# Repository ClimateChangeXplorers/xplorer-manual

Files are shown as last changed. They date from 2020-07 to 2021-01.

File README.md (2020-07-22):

# Xplorer Manual

The process for building your station follows 5 major steps:

1. [PLAN](/plan): in this step you will plan out the design of your
   station. The components, sensors, physical design, etc. will all be
   taken into account during this phase.
2. [BUILD](./build): in this step you will begin the building process.
   You will gather your frame parts, wires, and PVC and build the frame
   so it is ready for your sensors and microcontrollers.
3. [FLASH](./flash): in this step you will build the source files and
   flash them onto your device. Should you want to flash the binaries
   directly, there are instructions to do so.
4. [TEST](./test): making sure each node works as expected will insure
   the best experience for your deployment.
5. [DEPLOY](./deploy): siting and deploying are the final step in
   getting you on your way to your first 3d-printed automated weather
   station.

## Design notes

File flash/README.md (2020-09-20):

# Flashing Microcontrollers

Each station node is build atop a microcontroller, where each
microcontroller is connected to one or more sensors either directly or
by [Grove hubs](https://www.seeedstudio.com/Grove-I2C-Hub.html). 

The CCX system is designed to be used with the [m5Stack Atom Lite](https://m5stack.com/collections/m5-core/products/atom-lite-esp32-development-kit)
ESP32-Pico based microcontroller.  

There are two nodes that the core Arduino code has been developed for.
Before compiling the microcode onto the Arduino, you will also need to
install the core IoTwx shared library which controls many of the
communications and initialization functions of each node.

This core library can found at the following repository. It should be
installed in your `Arduiono/libraries` directory and once installed, you
may use it by the `#include "IoTwx.h"` directive.

* [https://github.com/NCAR/esp32-atomlite-arduino-iotwx](https://github.com/NCAR/esp32-atomlite-arduino-iotwx)

Please see the
[parts list](https://drive.google.com/file/d/1Hnn0Ms2DzVQgRFmGBpLQ9W2NGEz2gopc/view?usp=sharing)
for the microcontroller, sensors and cables required or recommended to
build and connect a base system.

## Preparing Your System

You will need to install the [latest version of Arduino](https://www.arduino.cc/en/Main/Software) on your system to begin.

There are a few other steps you will need to complete:

* install the required ESP32 Pico / M5 Stack Atom lite boards; a comprehensive instruction set is [here](https://docs.m5stack.com/#/en/arduino/arduino_development)
* install the [arduino-esp32fs-plugin](https://github.com/me-no-dev/arduino-esp32fs-plugin) that will allow SPIFFS file uploads to ESP32 boards
* install the following libraries through the Arduino IDE:
   * MQTT library from 256dpi [https://github.com/256dpi/arduino-mqtt](https://github.com/256dpi/arduino-mqtt)
   * SeeedStudio VEML6070 library [https://github.com/Seeed-Studio/Seeed_VEML6070](https://github.com/Seeed-Studio/Seeed_VEML6070)
   * SeeedStudio BME280 library [https://github.com/Seeed-Studio/Grove_BME280](https://github.com/Seeed-Studio/Grove_BME280)
   * SeeedStudio BME680 library [https://github.com/Seeed-Studio/Seeed_BME680](https://github.com/Seeed-Studio/Seeed_BME680)
   * ArduinoJson library [https://github.com/bblanchon/ArduinoJson](https://github.com/bblanchon/ArduinoJson)
   * FastLED library [https://github.com/FastLED/FastLED](https://github.com/FastLED/FastLED)
   * NTPClient library [https://github.com/arduino-libraries/NTPClient](https://github.com/arduino-libraries/NTPClient)

## Atmos Node 

The Atmos node is comprised of two sensors and two 3d-printed housing
units. The first sensor houses the atmospheric conditions for air
temperature, humidity and barometric pressure. It can be fitted with the
[Seeedstudio BME280 Grove](https://www.seeedstudio.com/Grove-BME280-Environmental-Sensor-Temperature-Humidity-Barometer.html)
environmental sensor, or if you would like to obtain aggregate VOC
measurements, you can fit the housing with the
[BME680 Grove](https://www.seeedstudio.com/Grove-Temperature-Humidity-Pressure-and-Gas-Sensor-for-Arduino-BME680.html)
sensor. The code is designed to work with both sensors (but not
simultaneously). These parts can be found in the
[parts list](https://drive.google.com/file/d/1Hnn0Ms2DzVQgRFmGBpLQ9W2NGEz2gopc/view?usp=sharing).

### Radiation Shield

atmos node

The radiation shield sensor captures the following measurements:
temperature, humidity, barometric pressure, and optionally VOC (if using
the BME680 sensor).

**PRINTING**

* the radiation shield design 3d print files can be found in the
  [`/build/stl/atmos`](https://github.com/ClimateChangeXplorers/xplorer-manual/tree/master/build/stl/atmos) page. If you need to
  print, you will need to follow the instructions there to print the
  housing.

**FLASHING**

* the code to flash the node can be found in the
  [esp32-atomlite-arduino-atmos-node repository](https://github.com/NCAR/esp32-atomlite-arduino-atmos-node).
  You will to follow the instructions there to understand the Arduino
  flashing requirements and procedures.

### UV 

Because the UV measurement is part of the Atmos node, the code already
includes the capability to capture and transmit measurements. It is
integrated in to the
[esp32-atomlite-arduino-atmos-node repository](https://github.com/NCAR/esp32-atomlite-arduino-atmos-node)
and hence no other changes or files are necessary to flash once that
file has been uploaded to the microcontroller.

## Hydro Node

hydro node
 
The hydro node is designed to collected and transmit precipitation
measurements.  

**PRINTING** 

* the rain gauge design 3d print files can be found in the
  [`/build/stl/hydro`](https://github.com/ClimateChangeXplorers/xplorer-manual/tree/master/build/stl/hydro)
  page. If you need to print, you will need to follow the instructions
  there to print the housing.

**FLASHING**

* the code to flash the node can be found in the
  [esp32-atomlite-arduino-hydro-node repository](https://github.com/NCAR/esp32-atomlite-arduino-hydro-node).
  You will to follow the instructions there to understand the Arduino
  flashing requirements and procedures.

## Aero Node

aero node

The aero node is designed to collect wind vane & anemometer wind speed
and direction.

* Instructions for printing and flashing are forthcoming.

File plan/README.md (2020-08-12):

# Planning your station

In general, planning your station is easy. While we recommend you use PVC for the 
main frame of the station, you may use any materials you like as long as they bind to 
the ABS/PLA plastic of the 3D-printed parts.

The base configuration of the station includes three nodes and the power (we'll 
consider the power a node as well moving forward).  You may reduce or expand those 
nodes based on your specific needs, but the base configuration will be assumed in 
this guide.

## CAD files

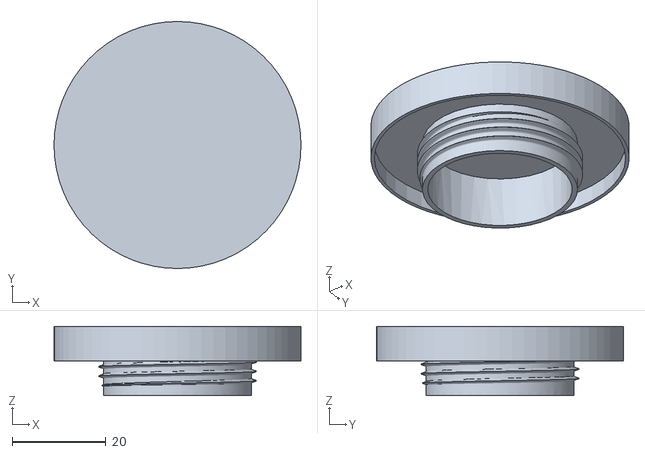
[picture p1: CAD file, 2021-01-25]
build/stl/aero/aero_wnvn_cap_2.stl
52.8 x 52.8 x 14.9

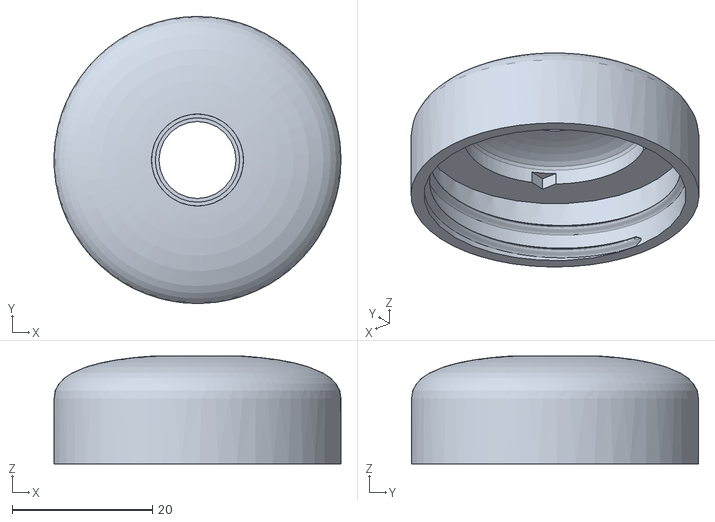
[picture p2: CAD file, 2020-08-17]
build/stl/atmos/uv_cap.stl
41.0 x 41.0 x 15.4

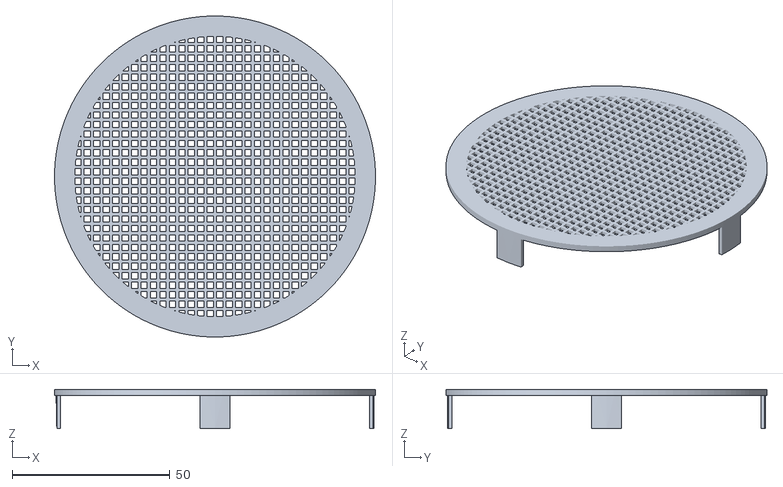
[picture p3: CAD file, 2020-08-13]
build/stl/hydro/hyd_funnel_screen.stl
101.9 x 101.9 x 12.5

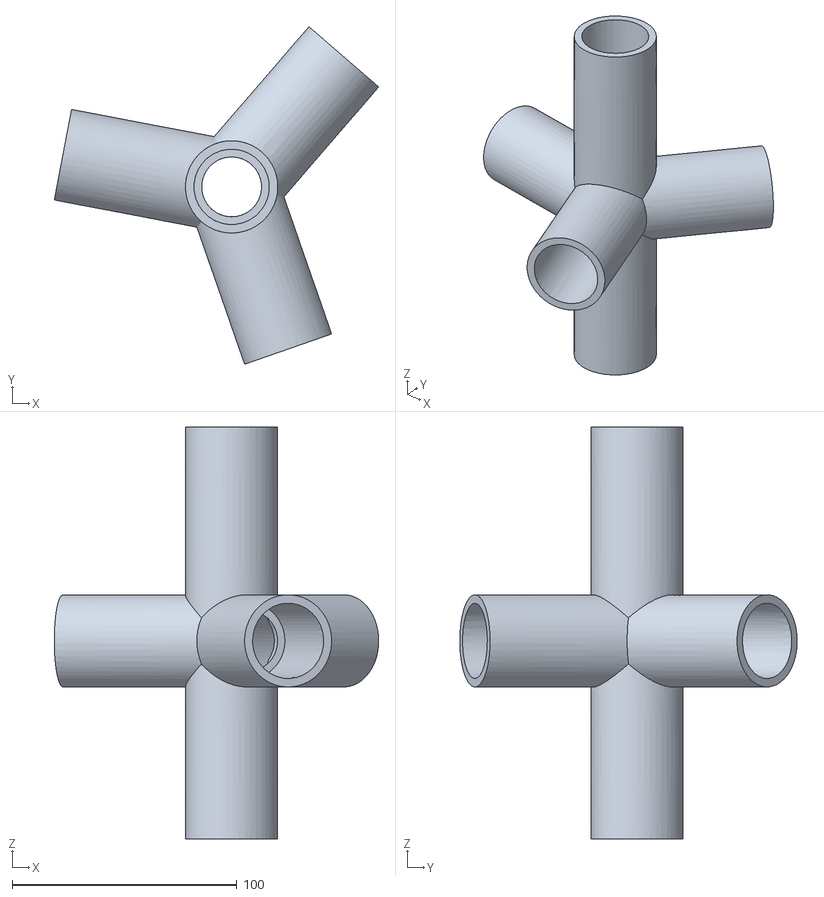
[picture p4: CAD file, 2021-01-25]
build/stl/pvc/pvc_mid_splitter.stl
144.2 x 150.0 x 183.1

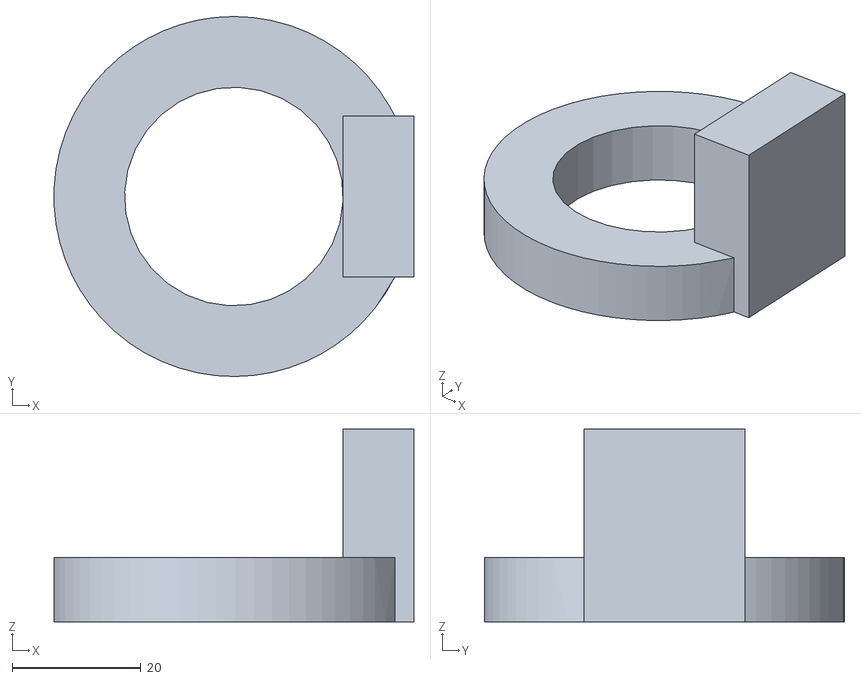
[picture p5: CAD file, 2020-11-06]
build/stl/solar/sol_11mil_clamp.stl
56.0 x 56.0 x 30.0

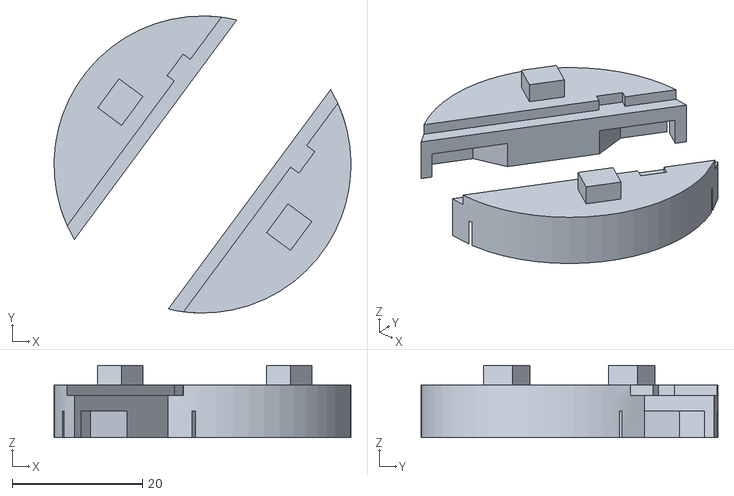
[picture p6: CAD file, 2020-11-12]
build/stl/aero/aero_wnvn_clips_3.stl
45.5 x 45.5 x 11.1

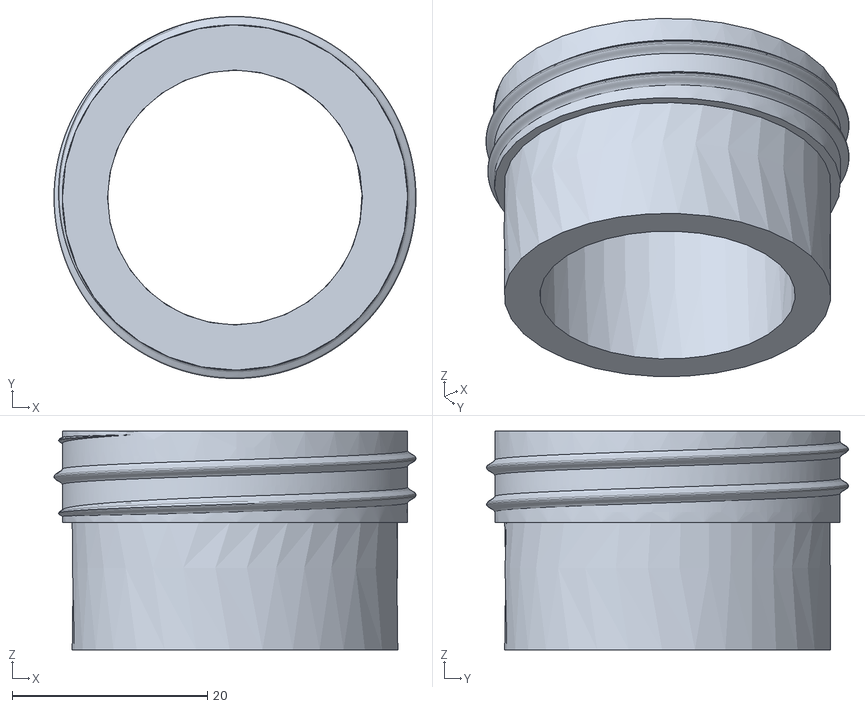
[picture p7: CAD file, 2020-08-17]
build/stl/atmos/uv_tube.stl
37.1 x 37.1 x 22.4

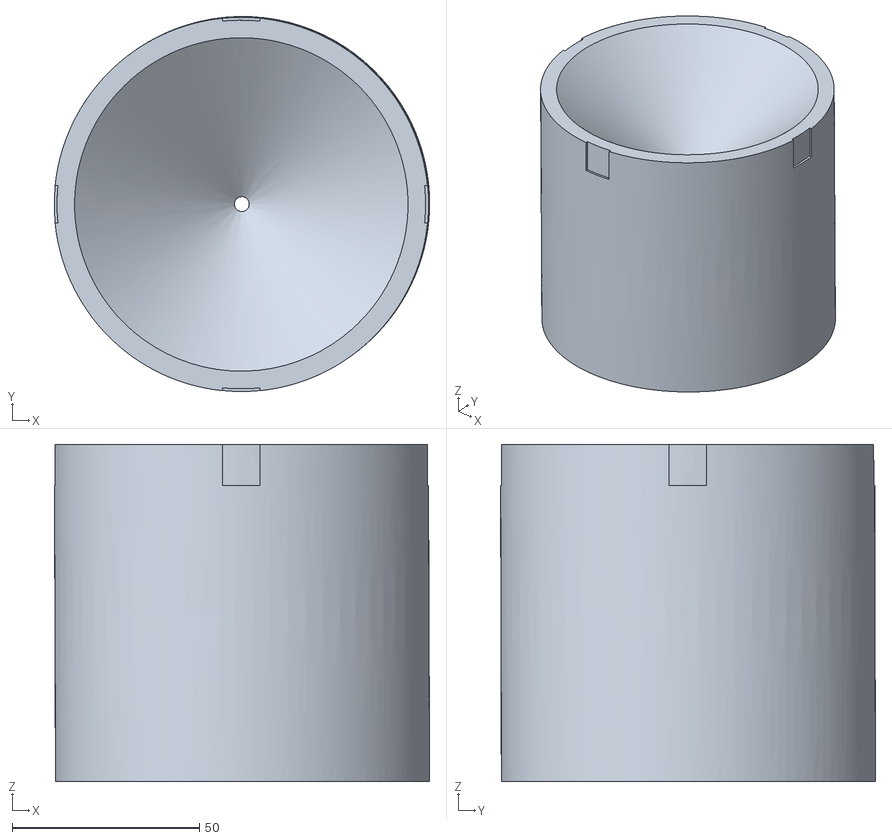
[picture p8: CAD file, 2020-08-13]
build/stl/hydro/hyd_funnel.stl
100.2 x 100.1 x 90.0

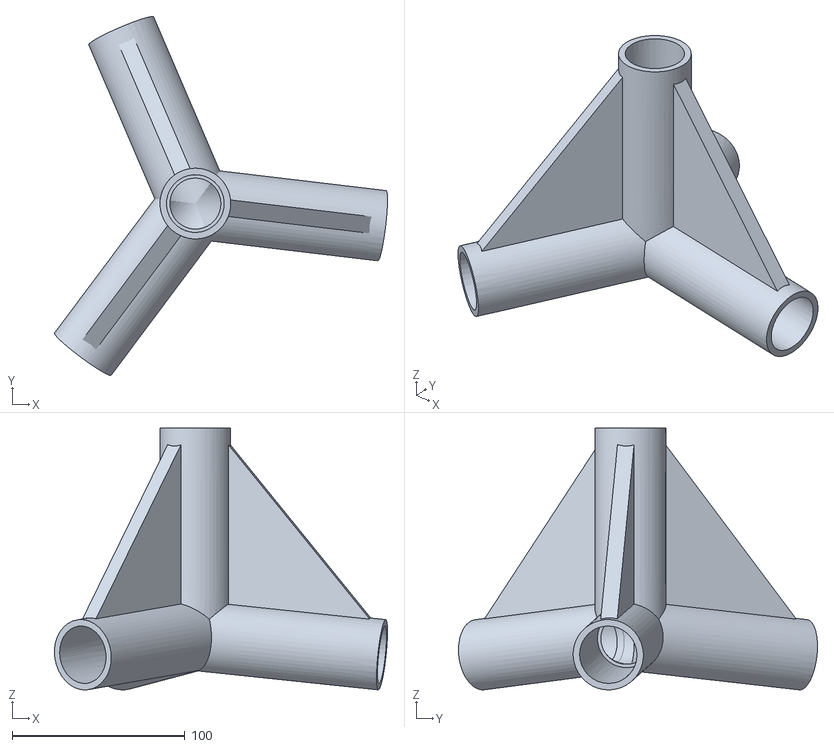
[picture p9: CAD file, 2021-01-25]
build/stl/pvc/pvc_tripod_base_2.stl
193.1 x 208.1 x 151.8

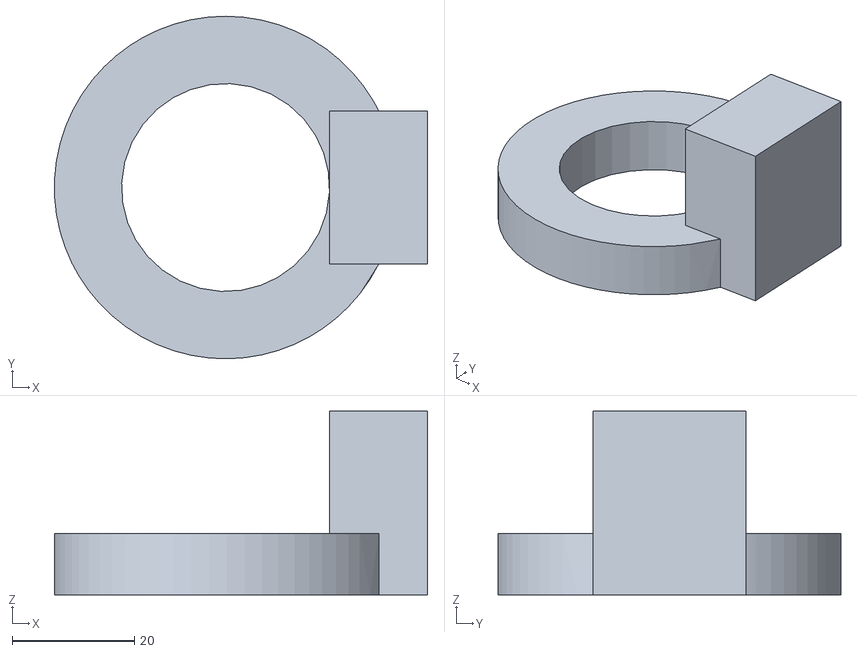
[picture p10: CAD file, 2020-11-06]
build/stl/solar/sol_16mil_clamp.stl
61.0 x 56.0 x 30.0

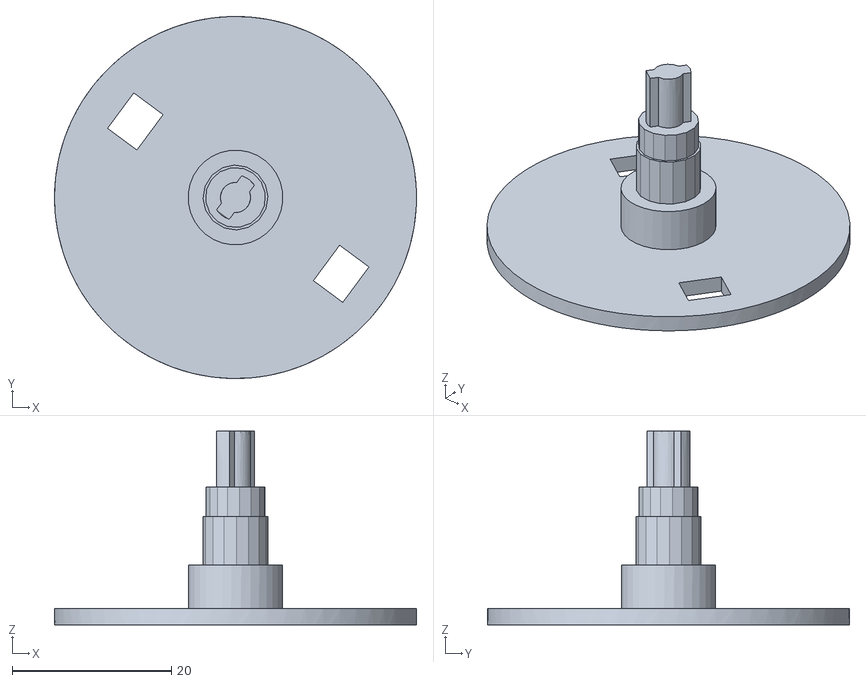
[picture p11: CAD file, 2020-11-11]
build/stl/aero/aero_wnvn_plate_3.stl
45.5 x 45.5 x 24.4

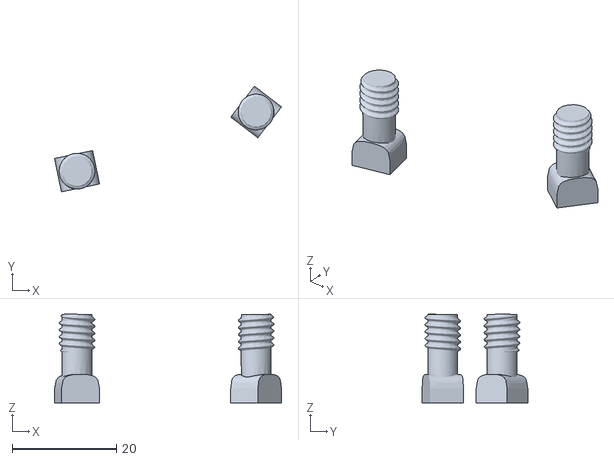
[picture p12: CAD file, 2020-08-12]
build/stl/atmos/rs_fasteners.stl
43.6 x 20.3 x 17.1

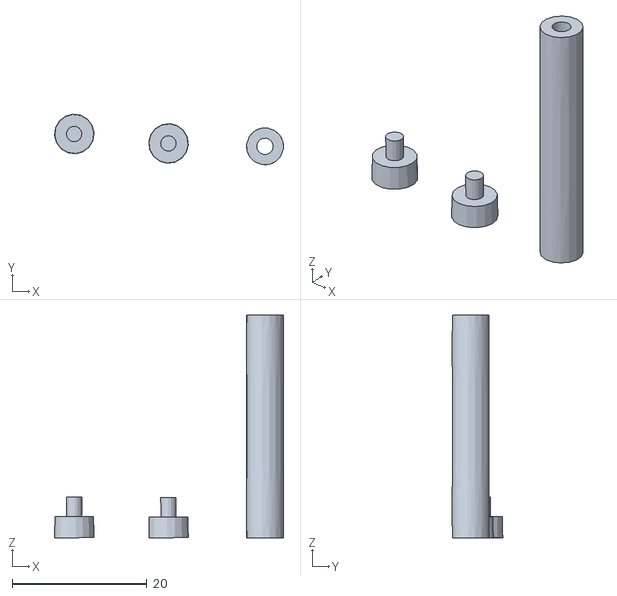
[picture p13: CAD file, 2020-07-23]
build/stl/hydro/hyd_fulcrum.stl
34.0 x 7.52 x 33.1

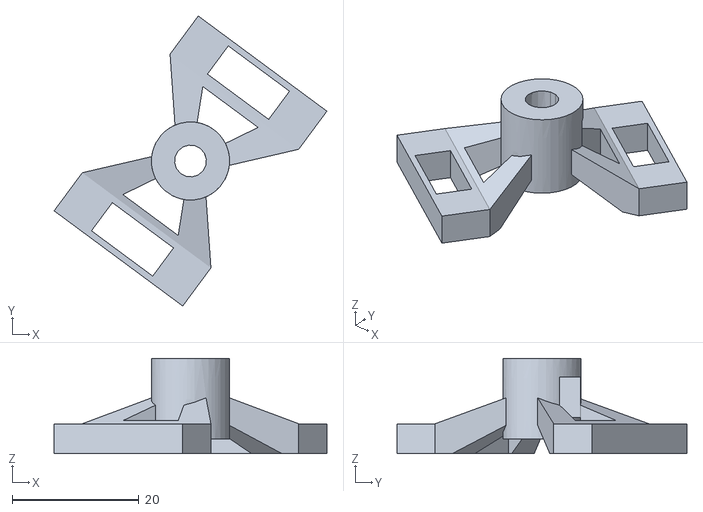
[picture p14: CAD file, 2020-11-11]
build/stl/aero/aero_wnvn_coupler_3.stl
43.1 x 45.8 x 15.0

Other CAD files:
build/stl/pvc/pvc_tri_splitter_2.stl
build/stl/atmos/rs_screen_ring.stl
build/stl/hydro/hyd_rain_guage.stl
build/stl/pvc/pvc_tripod_base_3.stl
build/stl/atmos/rs_base.stl
build/stl/atmos/rs_base_plate.stl
build/stl/atmos/rs_center_screen.stl
build/stl/atmos/rs_clip.stl
build/stl/atmos/rs_shaft.stl
build/stl/atmos/rs_single_leaf.stl
build/stl/atmos/rs_top_leaf.stl
build/stl/pvc/pvc_balljoint_bar.stl
build/stl/pvc/pvc_en_cap.stl
build/stl/pvc/pvc_en_tube.stl
build/stl/pvc/pvc_innerlock.stl
build/stl/pvc/pvc_micro_holder.stl
build/stl/pvc/pvc_outerlock.stl
build/stl/pvc/pvc_stake.stl
build/stl/pvc/pvc_tjoint.stl
build/stl/pvc/pvc_tri_splitter.stl
build/stl/pvc/pvc_tripod_base.stl

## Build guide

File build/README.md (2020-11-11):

# Building Your Station
atmos node

**PARTS LIST**

Before getting started, you should consult the complete list of parts
and hardware that can be found at:

* See the
  [Google spreadsheet](https://drive.google.com/file/d/1Hnn0Ms2DzVQgRFmGBpLQ9W2NGEz2gopc/view?usp=sharing)
  for the full, up-to-date list of _non-printed_ parts for building a
  complete station. The vast majority of parts can be found on Amazon,
  through online electronics distributors and through your local
  hardware store.

**Note:** the base case build has quantities preset to 1 item. Also,
**alternative power options** are also listed in this document for users
interested in further customizing their station to specific power needs.

If you only wish to do tabletop testing, you will only need to follow
the [flash instructions](https://github.com/ClimateChangeXplorers/xplorer-manual/tree/master/flash) for the microcontroller and then proceed to
the [tabletop testing](#skeletontabletop-testing). This will eliminate
the need for making wiring bundles, constructing a PVC frame or printing
the 3d-printed housing.

## 3D-Printing

All parts can be found in the [stl](./stl) folder and in conjection 
with the station assembly instructions.

Reference stations have been produced with PLA+ material, but
ABS and other materials may be used, provided you have 
enough expertise using them.

## Framing

## Wiring

## Station Assembly

You can find the various assembly instructions in the provided PDF files:

* [Aero Node Assembly](./Aero_Node_Assembly.pdf) instruction set
* [Hydro Node Assembly](./Hydro_Node_Assembly.pdf) instruction set
* [Atmos Node Assembly](./Atmos_Node_Assembly.pdf) instruction set

## Skeleton/Tabletop Testing

## Solar Assembly

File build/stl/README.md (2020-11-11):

# STL files for printing

There are directories containing all the STL files necessary to print the 
station.  The following nodes are available for printing.  Please consult
the [parts list](https://drive.google.com/file/d/1Hnn0Ms2DzVQgRFmGBpLQ9W2NGEz2gopc/view?usp=sharing) and [flash instructions](https://github.com/ClimateChangeXplorers/xplorer-manual/tree/master/flash) for the other parts (electronics, etc.) 
and code that are necessary to construct a fully operational node.

* [atmos node files](./atmos) are available for the radiation shield
* [hydro node files](./hydro) are available for the tipping bucket
* [aero node files](./aero) are available for the wind vane and anemometer 
* [solar assembly files](./solar) are available for the solar panel assembly
* [pvc connectors files](./pvc) are available for the pvc connectors

# Acknowledgements

This design would not have been possible without the enumerable contributions of others.

In particular, the Atmos node is inspired by the work of the [3D-PAWS radiation shield assembly](https://sites.google.com/ucar.edu/3dpaws/instruments/radiation-shield) ((c) UCAR/COMET)
from which modifications were made to accommodate different sensor orientations, to allow
for easier insertion of the leaf screens and changes were made to the shaft for 
improved threading and durability. The Hydro node is remixed and modified from the 
original work of [RobWLake's LTB Weather Station](https://www.thingiverse.com/thing:2849562) 
(CC-BY-NC 4.0) -- changes were made to the sensor holder to accommodate a [Grove hall effect sensor](https://wiki.seeedstudio.com/Grove-Hall_Sensor/) and a debris screen, 
as well as sizing modifications so that it is easier to construct.

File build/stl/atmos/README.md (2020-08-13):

# Print Settings

Unless otherwise noted, **infill default is 50%**.

| Description | File | Quantity | Notes |
|---|---|---|---|
| Base | [rs_base.stl](./rs_base.stl) | 1 | |
| Center Screen | [rs_center_screen.stl](./rs_center_screen.stl) | 1 | |
| Sensor clip holder | [rs_clip.stl](./rs_clip.stl) | 1 | Print more than 1 if you have multiples or need extras. |
| Middle leaf | [rs_mid_leaf.stl](./rs_mid_leaf.stl) | 1 | |
| Screen Ring | [rs_screen_ring.stl](./rs_screen_ring.stl) | 4 | |
| Center shaft | [rs_shaft.stl](./rs_shaft.stl) | 1 | Print at 100% infill |
| Single leaf | [rs_single_leaf.stl](./rs_single_leaf.stl) | 1 | |
| Top leaf | [rs_top_leaf.stl](./rs_top_leaf.stl) | 1 | |
| Base Fasteners | [rs_fasteners.stl](./rs_fasteners.stl) | 2 | Print at 100% infill; print extras as needed. |  | |
| Swivel ball joint connector | [swvl_balljoint_bar.stl](./swvl_balljoint_bar.stl) | 1 | |
| Swivel ball joint inner locl |[swvl_innerlock.stl](./swvl_innerlock.stl) | 1 | |
| Swivel ball joint outer lock | [swvl_outerlock.stl](./swvl_outerlock.stl) | 1 | |
| Microcontroller holder  | [pvc_micro_holder.stl](./pvc_micro_holder.stl) | 1 | |

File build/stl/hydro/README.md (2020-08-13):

# Print Settings

Unless otherwise noted, **infill default is 50%**.

| Description | File | Quantity | Notes |
|---|---|---|---|
| Fulcrum | [hyd_fulcrum.stl](./hyd_fulcrum.stl) | 1 | Print more than 1 if you need extras |
| Funnel Screen | [hyd_funnel_screen.stl](./hyd_funnel_screen.stl) | 1 | |
| Funnel | [hyd_funnel.stl](./hyd_funnel.stl) | 1 |  |
| Rain gauge | [hyd_rain_guage.stl](./hyd_rain_guage.stl) | 1 | |
| Sensor Slot | [hyd_sensor_slot.stl](./hyd_sensor_slot.stl) | 1 |  |
| Swivel ball joint connector | [swvl_balljoint_bar.stl](./swvl_balljoint_bar.stl) | 1 | |
| Swivel ball joint inner locl |[swvl_innerlock.stl](./swvl_innerlock.stl) | 1 | |
| Swivel ball joint outer lock | [swvl_outerlock.stl](./swvl_outerlock.stl) | 1 | |
| Microcontroller holder  | [pvc_micro_holder.stl](./pvc_micro_holder.stl) | 1 | |

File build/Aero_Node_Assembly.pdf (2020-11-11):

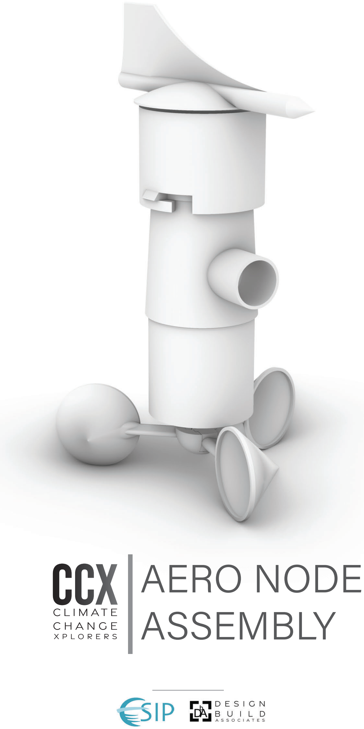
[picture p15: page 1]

# AERO NODE ASSEMBLY Climate

Change
xplorers

# CCX

Climate
Change
xplorers

## EXPLODED COMPONENTS

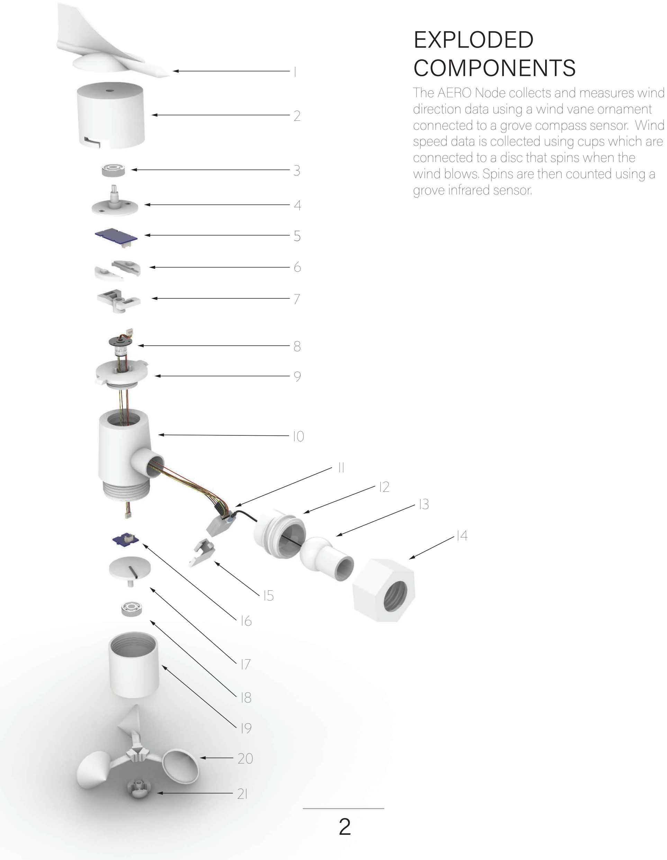
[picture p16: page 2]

The AERO Node collects and measures wind direction data using a wind vane ornament connected to a grove compass sensor. Wind speed data is collected using cups which are connected to a disc that spins when the wind blows. Spins are then counted using a grove infrared sensor.

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
## COMPONENTS LIST

## ASSEMBLY

# | DESCRITION | QUANTITY

1 | Ornament | 1
2 | Wind Vane Hull | 1
3 | Wind Vane Bearing | 1
4 | Wind Vane Plate | 1
5 | Grove Compass Sensor | 1
6 | Wind Vane Plate Clips | 1
7 | Wind Vane Coupler | 1
8 | Comidox Slip Ring Capsole | 1
9 | Wind Vane Cap | 1
10 | Center Hull | 1
11 | Microprocessor | 1
12 | Swivel Innerlock | 1
13 | Swivel Ball Joint Bar | 1
14 | Swivel Outerlock | 1
15 | Micro Harness | 1
16 | Wind Speed Plate | 1
17 | Grove Infrared Sensor | 1
18 | Wind Speed Bearing | 1
19 | Wind Speed Hull | 1
20 | Wind Speed Cups | 1
21 | Wind Speed Cup Connector | 1

# STEP 1

Align the slots on the cap connector with the groves on the cups and connect them one at a time.

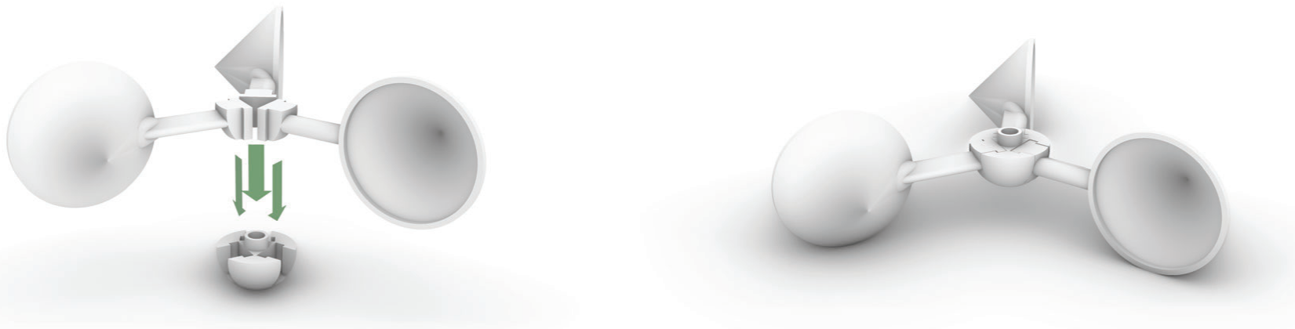
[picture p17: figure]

## ASSEMBLY

# STEP 2

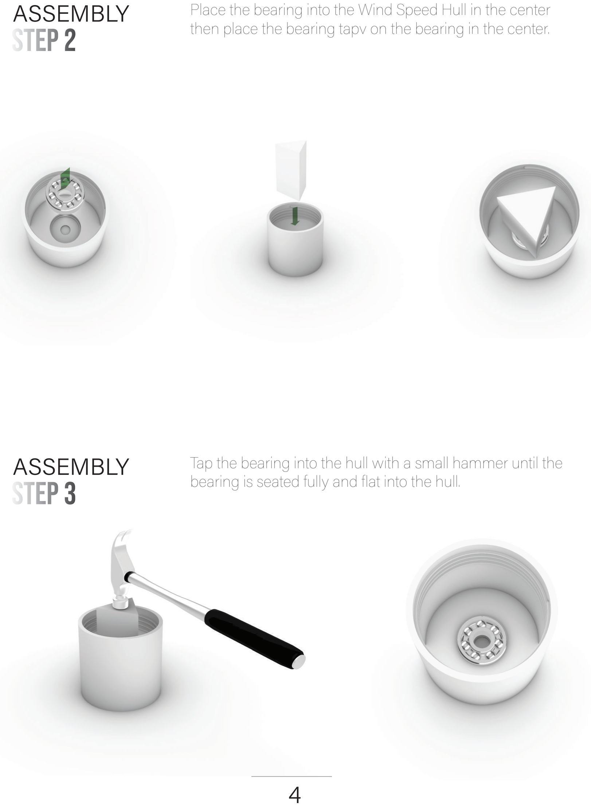
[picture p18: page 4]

## ASSEMBLY

# STEP 3

Tap the bearing into the hull with a small hammer until the bearing is seated fully and flat into the hull.

Place the bearing into the Wind Speed Hull in the center then place the bearing tapv on the bearing in the center.

# STEP 4

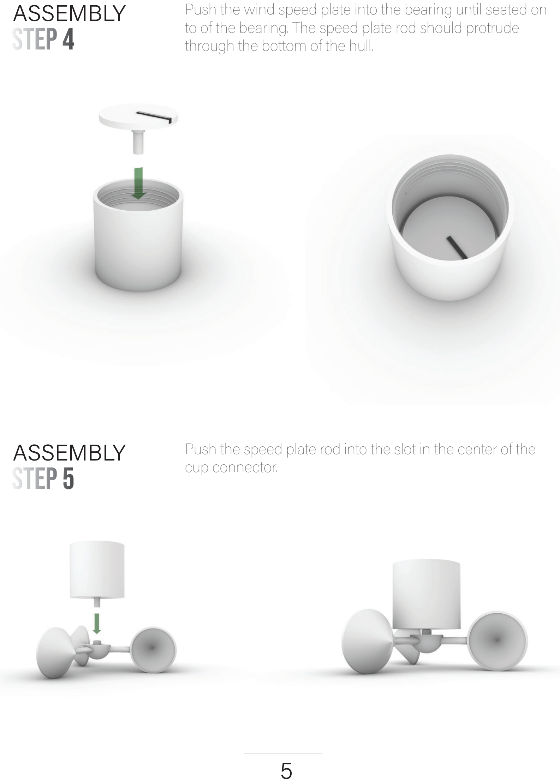
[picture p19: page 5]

## ASSEMBLY

# STEP 5

Push the speed plate rod into the slot in the center of the cup connector.

Push the wind speed plate into the bearing until seated on to of the bearing. The speed plate rod should protrude through the bottom of the hull.

# STEP 6

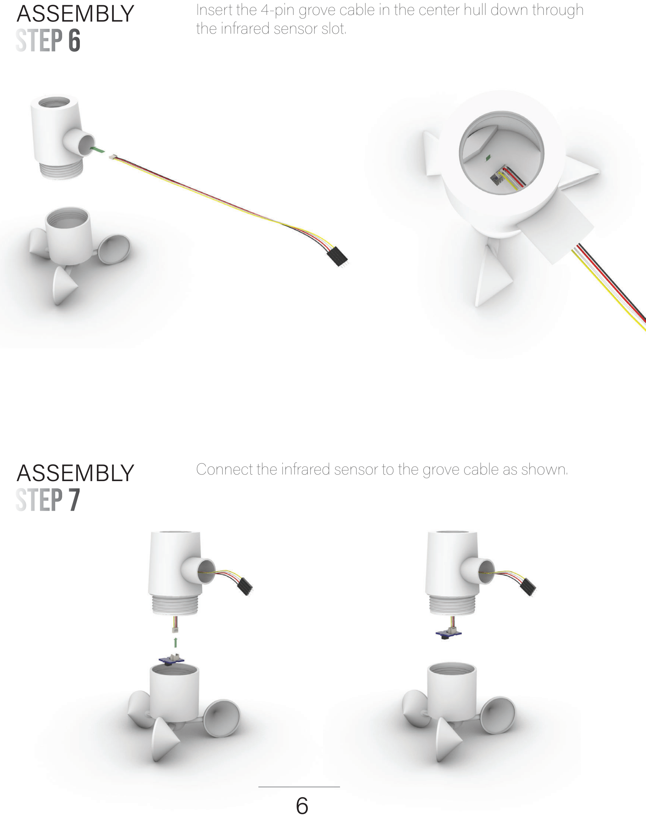
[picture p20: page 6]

## ASSEMBLY

# STEP 7

Connect the infrared sensor to the grove cable as shown.

Insert the 4-pin grove cable in the center hull down through the infrared sensor slot.

# STEP 8

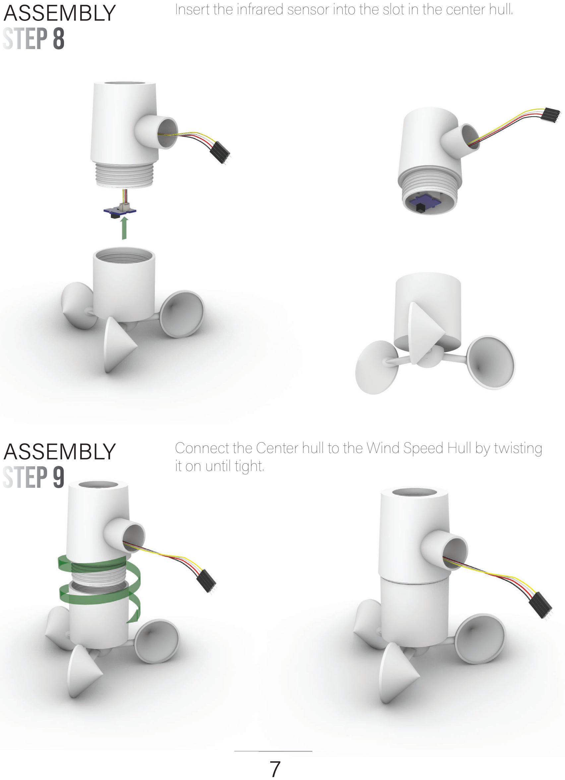
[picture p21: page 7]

## ASSEMBLY

Connect the Center hull to the Wind Speed Hull by twisting it on until tight.

Insert the infrared sensor into the slot in the center hull.

# STEP 10

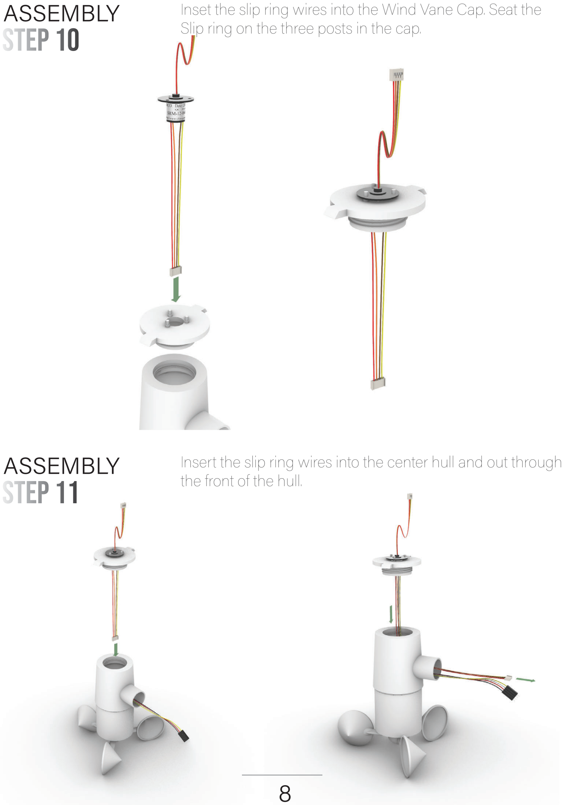
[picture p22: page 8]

## ASSEMBLY

# STEP 11

Insert the slip ring wires into the center hull and out through the front of the hull.

Inset the slip ring wires into the Wind Vane Cap. Seat the Slip ring on the three posts in the cap.

# STEP 12

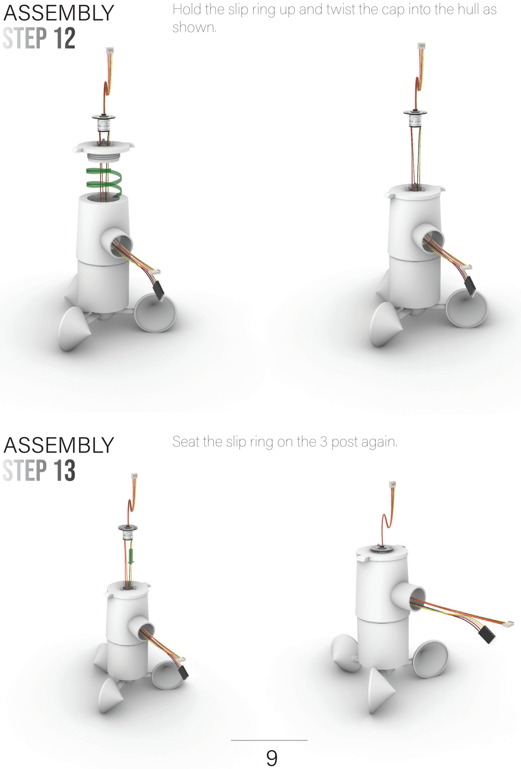
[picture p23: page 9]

## ASSEMBLY

Seat the slip ring on the 3 post again.

Hold the slip ring up and twist the cap into the hull as shown.

# STEP 14

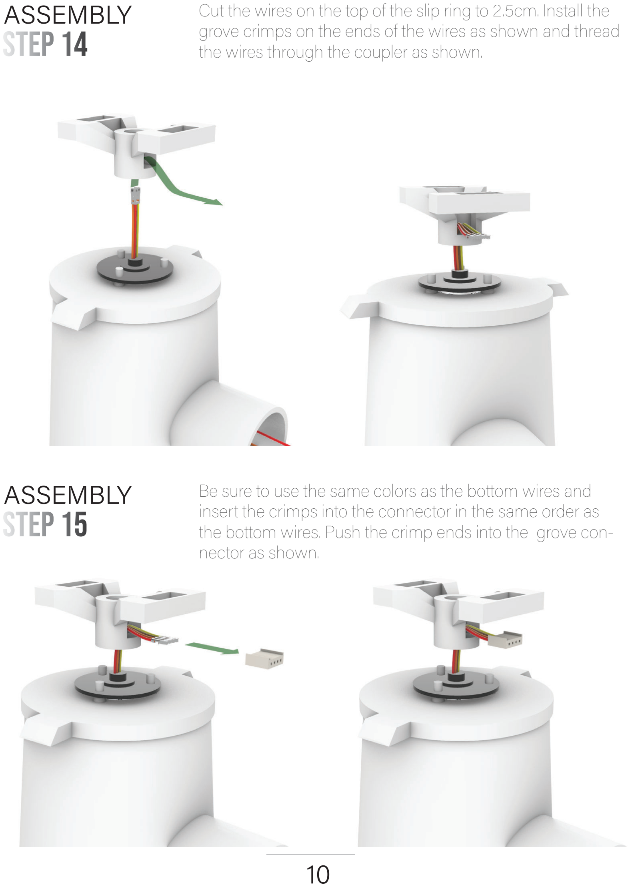
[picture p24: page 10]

## ASSEMBLY

# STEP 15

Be sure to use the same colors as the bottom wires and insert the crimps into the connector in the same order as the bottom wires. Push the crimp ends into the grove connector as shown.

Cut the wires on the top of the slip ring to 2.5cm. Install the grove crimps on the ends of the wires as shown and thread the wires through the coupler as shown.

# STEP 16

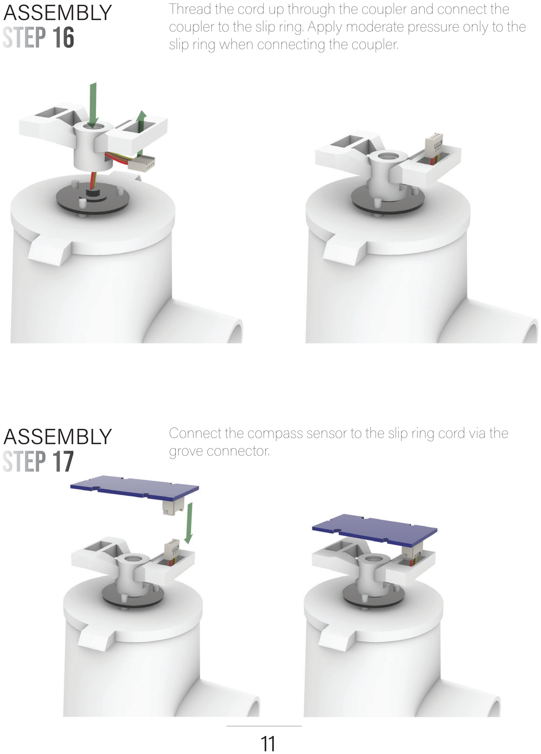
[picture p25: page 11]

## ASSEMBLY

# STEP 17

Connect the compass sensor to the slip ring cord via the grove connector.

Thread the cord up through the coupler and connect the coupler to the slip ring. Apply moderate pressure only to the slip ring when connecting the coupler.

# STEP 18

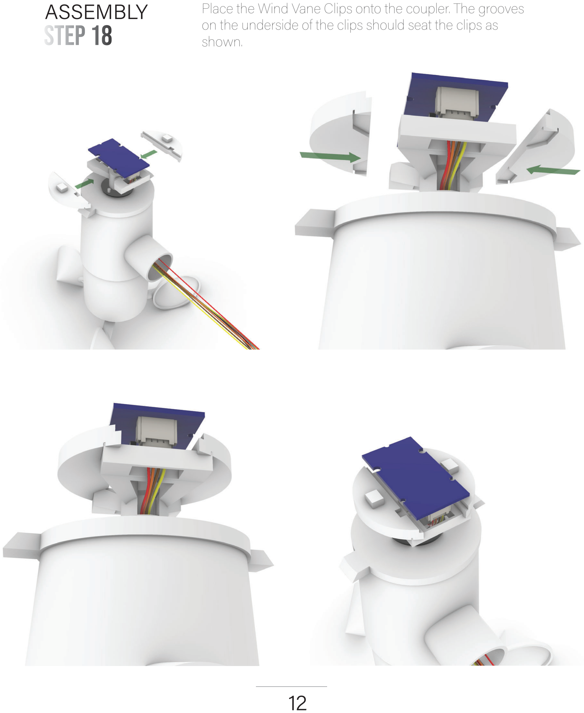
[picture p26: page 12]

Place the Wind Vane Clips onto the coupler. The grooves on the underside of the clips should seat the clips as shown.

# STEP 19

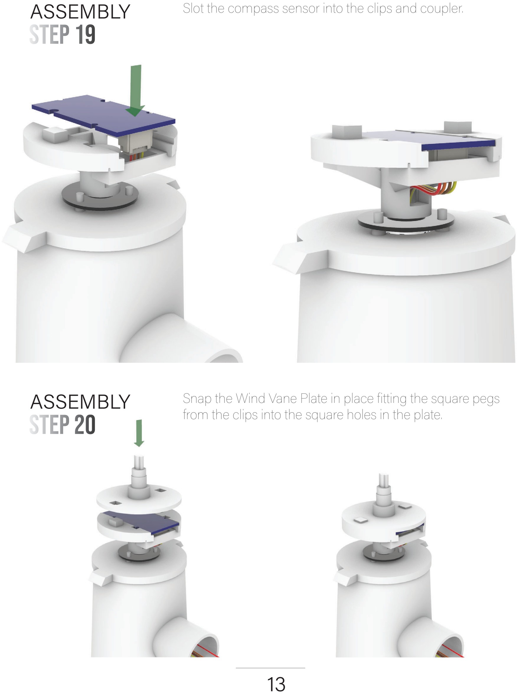
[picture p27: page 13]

## ASSEMBLY

# STEP 20

Snap the Wind Vane Plate in place fitting the square pegs from the clips into the square holes in the plate.

Slot the compass sensor into the clips and coupler.

# STEP 21

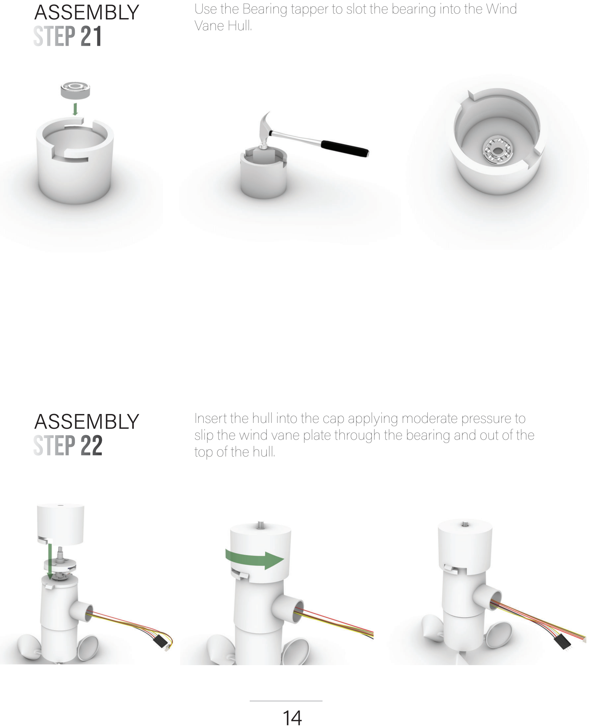
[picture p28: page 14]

## ASSEMBLY

# STEP 22

Insert the hull into the cap applying moderate pressure to slip the wind vane plate through the bearing and out of the top of the hull.

Use the Bearing tapper to slot the bearing into the Wind Vane Hull.

# STEP 23

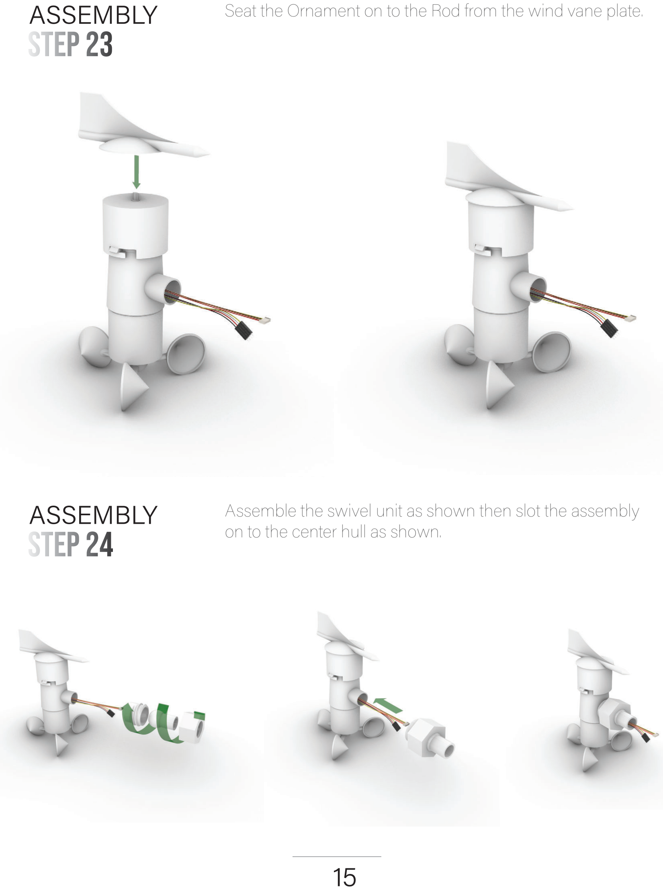
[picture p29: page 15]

## ASSEMBLY

# STEP 24

Assemble the swivel unit as shown then slot the assembly on to the center hull as shown.

Seat the Ornament on to the Rod from the wind vane plate.

# STEP 25

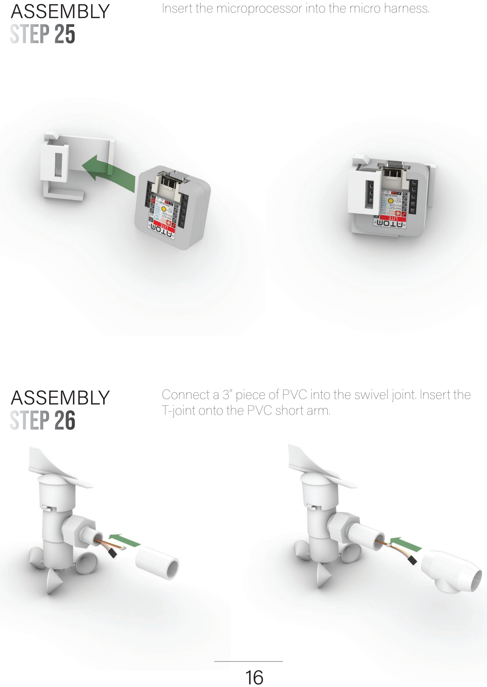
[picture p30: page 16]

## ASSEMBLY

# STEP 26

Connect a 3” piece of PVC into the swivel joint. Insert the T-joint onto the PVC short arm.

Insert the microprocessor into the micro harness.

# STEP 27

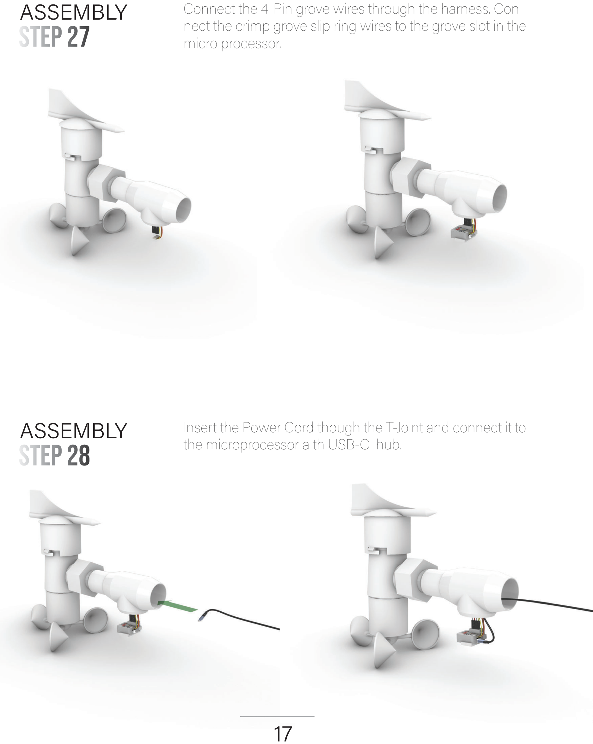
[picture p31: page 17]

## ASSEMBLY

# STEP 28

Insert the Power Cord though the T-Joint and connect it to the microprocessor a th USB-C hub.

Connect the 4-Pin grove wires through the harness. Connect the crimp grove slip ring wires to the grove slot in the micro processor.

# STEP 29

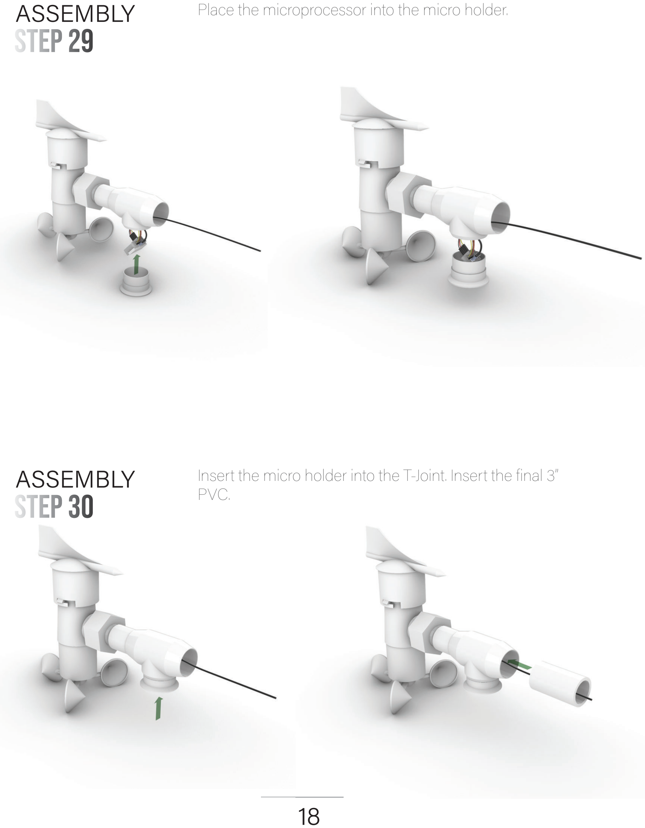
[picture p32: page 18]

## ASSEMBLY

# STEP 30

Insert the micro holder into the T-Joint. Insert the final 3” PVC.

Place the microprocessor into the micro holder.

# COMPLETE

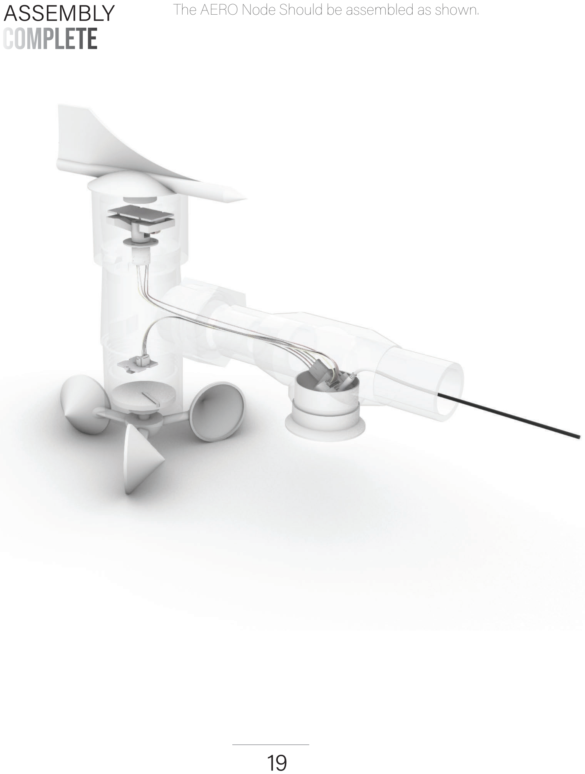
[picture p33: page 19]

The AERO Node Should be assembled as shown.

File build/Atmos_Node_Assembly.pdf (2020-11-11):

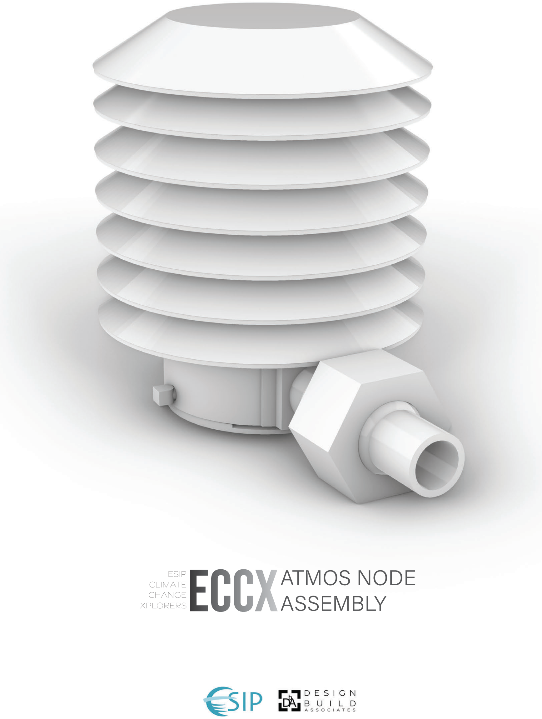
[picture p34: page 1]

## ATMOS NODE ECCXASSEMBLY

esip
Climate
Change
xplorers

## EXPLODED COMPONENTS

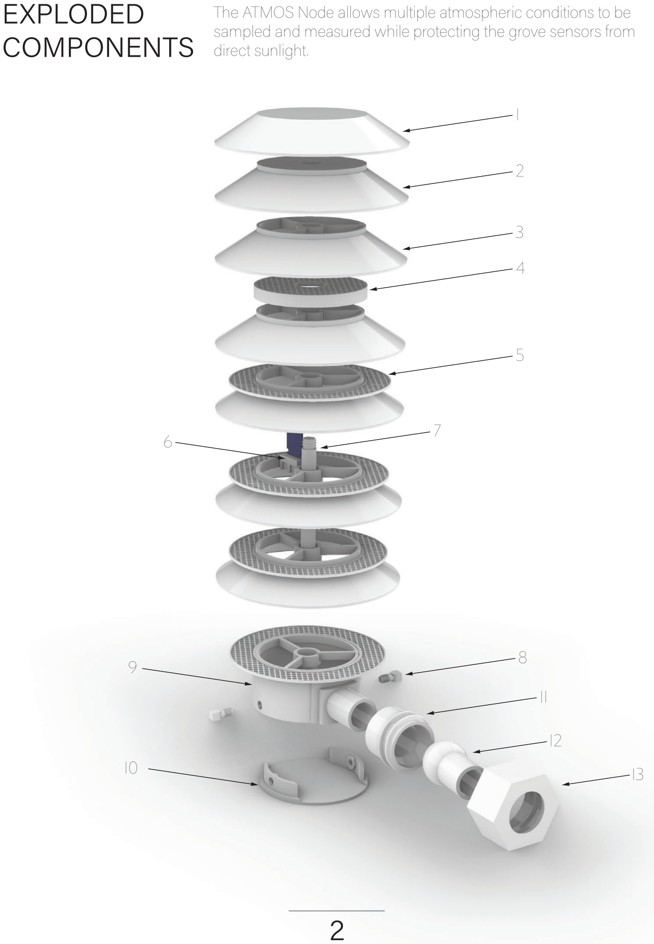
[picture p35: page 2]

The ATMOS Node allows multiple atmospheric conditions to be sampled and measured while protecting the grove sensors from direct sunlight.

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
## COMPONENTS LIST

## ASSEMBLY

# | DESCRITION | QUANTITY

1 | Top Leaf | 1
2 | Single Leaf | 1
3 | Mid Leaf | 5
4 | Center Screen | 1
5 | Screen Ring | 4
6 | Sensor Clip | 1
7 | Shaft | 1
8 | Fastener | 2
9 | Base | 1
10 | Base Plate | 1
11 | Swivel Innerlock | 1
12 | Swivel Ball Joint Bar | 1
13 | Swivel Outerlock | 1

# STEP 1

Attach Base Plate to Base with 2 Fasteners. Make sure Base Plate threads are lined up with Base holes.

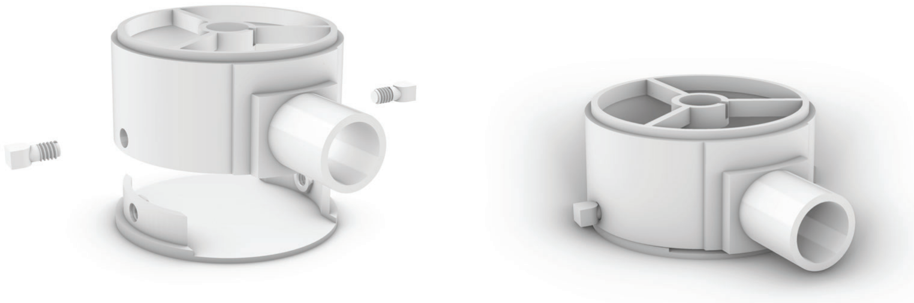
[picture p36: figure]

## ASSEMBLY

# STEP 2

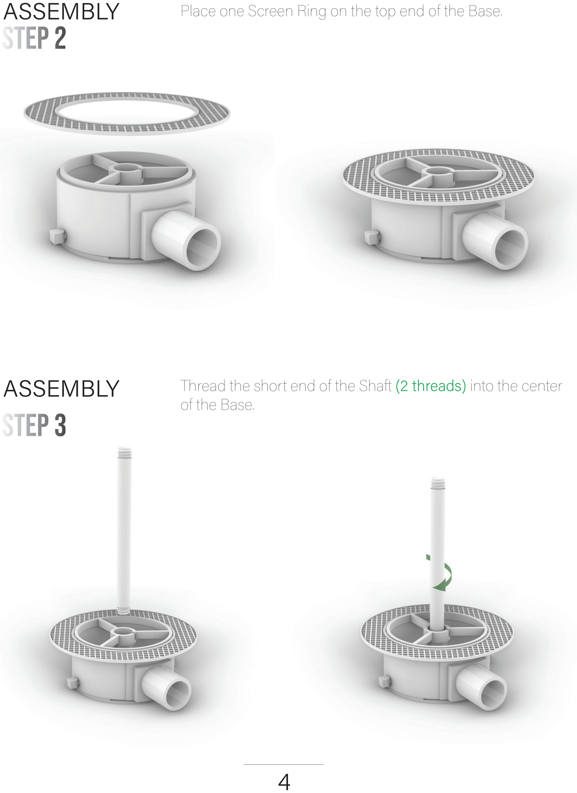
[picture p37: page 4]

Place one Screen Ring on the top end of the Base.

## ASSEMBLY

# STEP 3

Thread the short end of the Shaft (2 threads) into the center of the Base.

## ASSEMBLY

# STEP 4

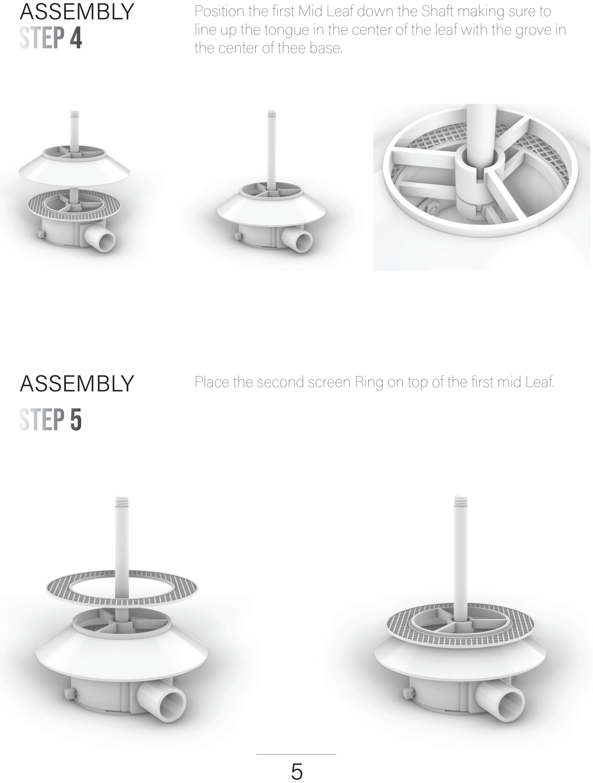
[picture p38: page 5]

Position the first Mid Leaf down the Shaft making sure to line up the tongue in the center of the leaf with the grove in the center of thee base.

## ASSEMBLY

# STEP 5

Place the second screen Ring on top of the first mid Leaf.

## ASSEMBLY

# STEP 6

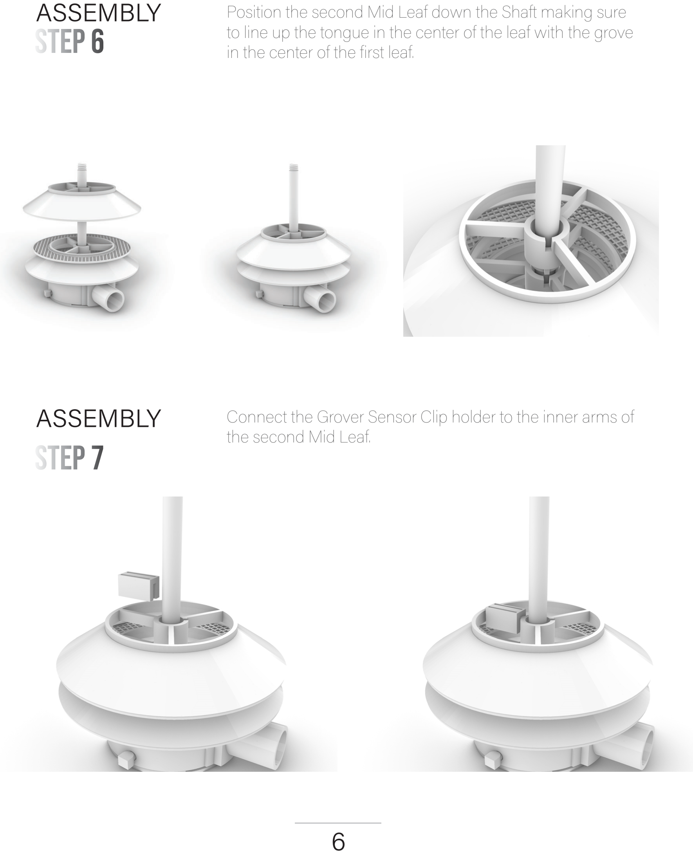
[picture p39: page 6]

Position the second Mid Leaf down the Shaft making sure to line up the tongue in the center of the leaf with the grove in the center of the first leaf.

## ASSEMBLY

# STEP 7

Connect the Grover Sensor Clip holder to the inner arms of the second Mid Leaf.

## ASSEMBLY

# STEP 8

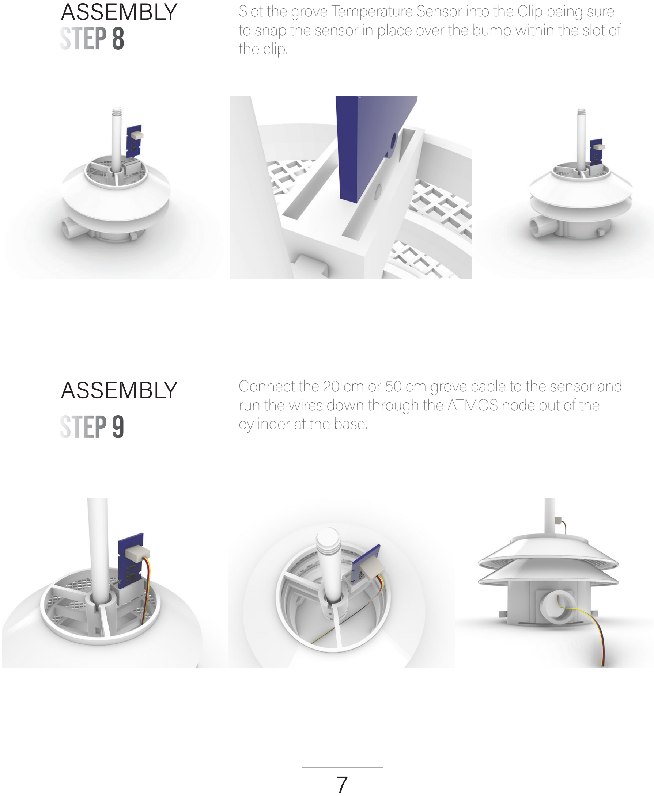
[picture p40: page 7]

Slot the grove Temperature Sensor into the Clip being sure to snap the sensor in place over the bump within the slot of the clip.

## ASSEMBLY

# STEP 9

Connect the 20 cm or 50 cm grove cable to the sensor and run the wires down through the ATMOS node out of the cylinder at the base.

## ASSEMBLY

# STEP 10

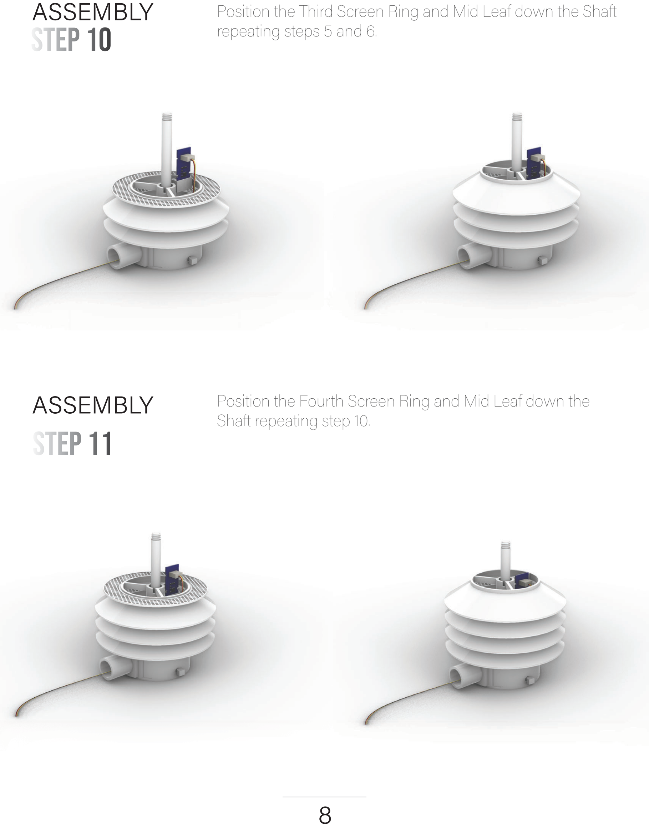
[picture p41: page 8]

Position the Third Screen Ring and Mid Leaf down the Shaft repeating steps 5 and 6.

## ASSEMBLY

# STEP 11

Position the Fourth Screen Ring and Mid Leaf down the Shaft repeating step 10.

## ASSEMBLY

# STEP 12

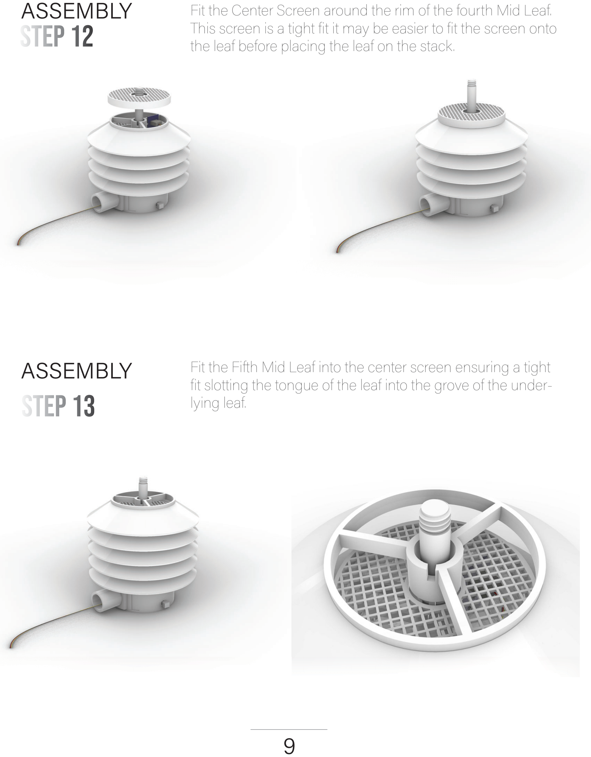
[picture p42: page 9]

Fit the Center Screen around the rim of the fourth Mid Leaf. This screen is a tight fit it may be easier to fit the screen onto the leaf before placing the leaf on the stack.

## ASSEMBLY

# STEP 13

Fit the Fifth Mid Leaf into the center screen ensuring a tight fit slotting the tongue of the leaf into the grove of the underlying leaf.

## ASSEMBLY

# STEP 14

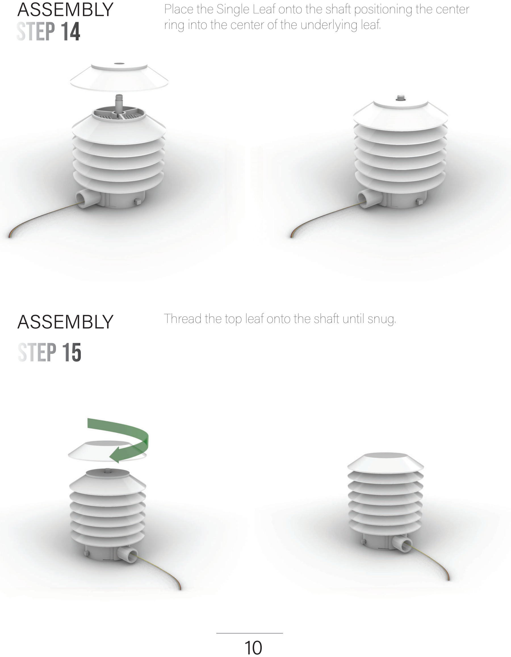
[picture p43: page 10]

Place the Single Leaf onto the shaft positioning the center ring into the center of the underlying leaf.

## ASSEMBLY

# STEP 15

Thread the top leaf onto the shaft until snug.

## ASSEMBLY

# STEP 16

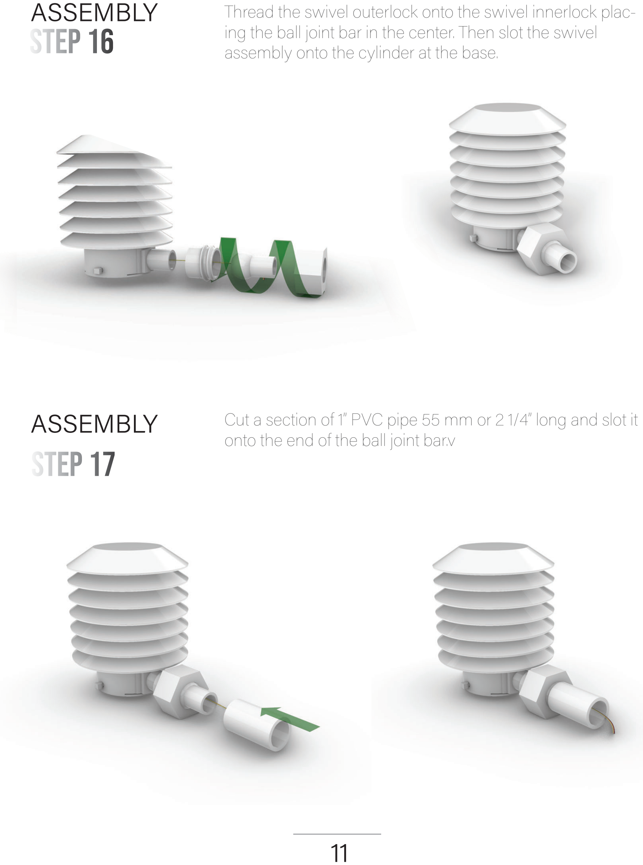
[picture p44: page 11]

Thread the swivel outerlock onto the swivel innerlock placing the ball joint bar in the center. Then slot the swivel assembly onto the cylinder at the base.

## ASSEMBLY

# STEP 17

Cut a section of 1” PVC pipe 55 mm or 2 1/4” long and slot it onto the end of the ball joint bar.v

## ASSEMBLY

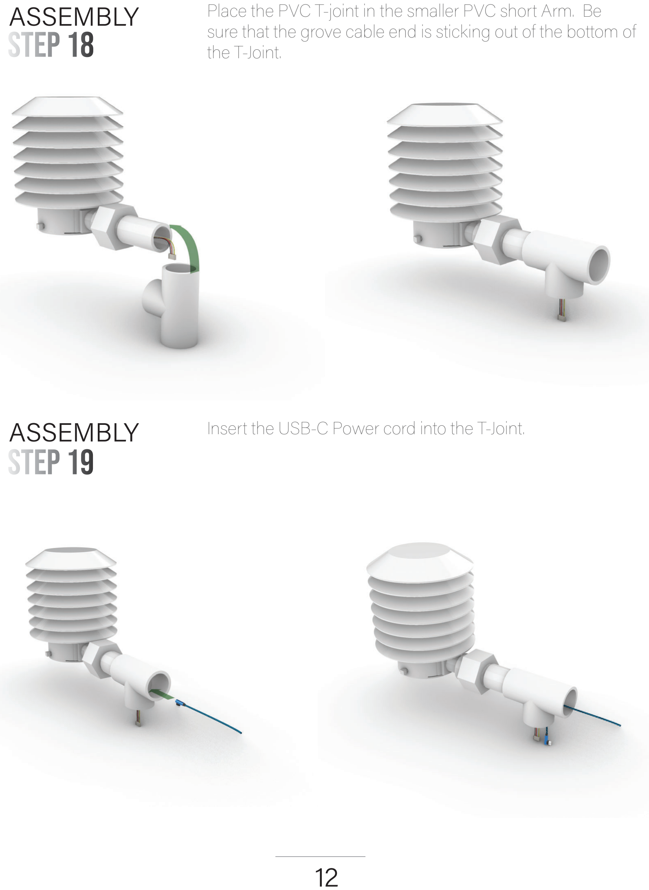
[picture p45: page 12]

## ASSEMBLY

Insert the USB-C Power cord into the T-Joint.

# STEP 19

Place the PVC T-joint in the smaller PVC short Arm. Be
sure that the grove cable end is sticking out of the bottom of STEP 18 | the T-Joint.

## ASSEMBLY

# STEP 20

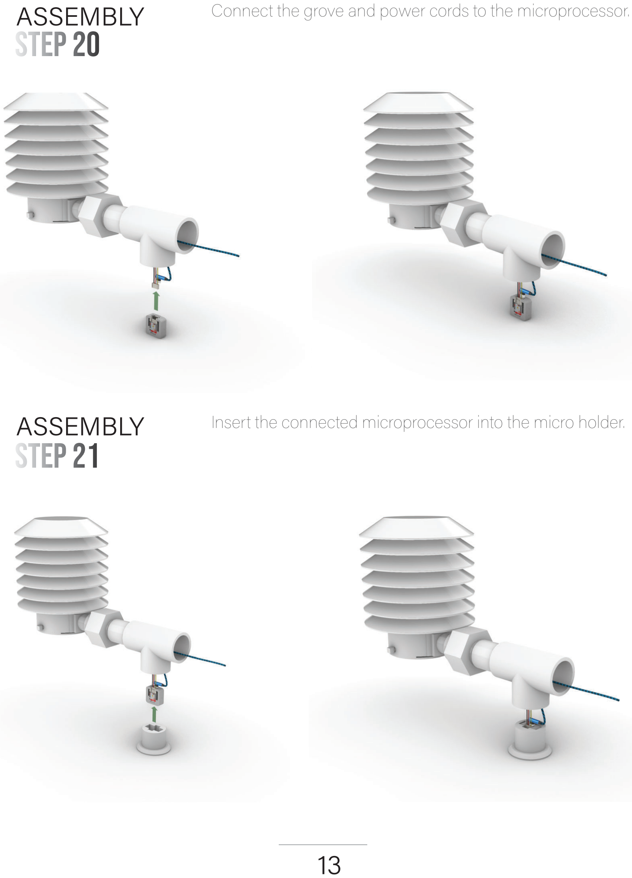
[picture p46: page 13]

## ASSEMBLY

Insert the connected microprocessor into the micro holder.

# STEP 21

Connect the grove and power cords to the microprocessor.

## ASSEMBLY

# STEP 22

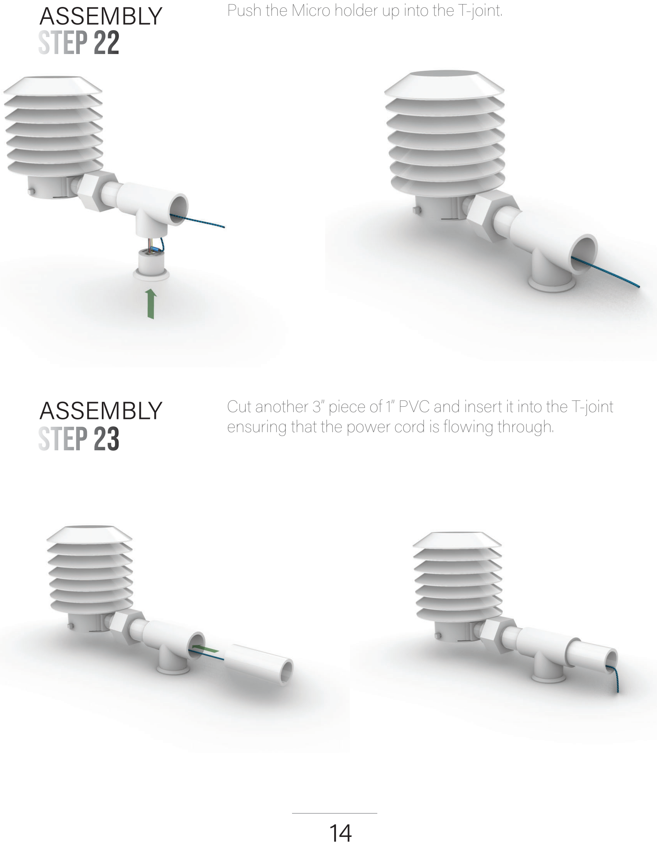
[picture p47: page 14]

## ASSEMBLY

Cut another 3” piece of 1” PVC and insert it into the T-joint ensuring that the power cord is flowing through. STEP 23

Push the Micro holder up into the T-joint.

# COMPLETE

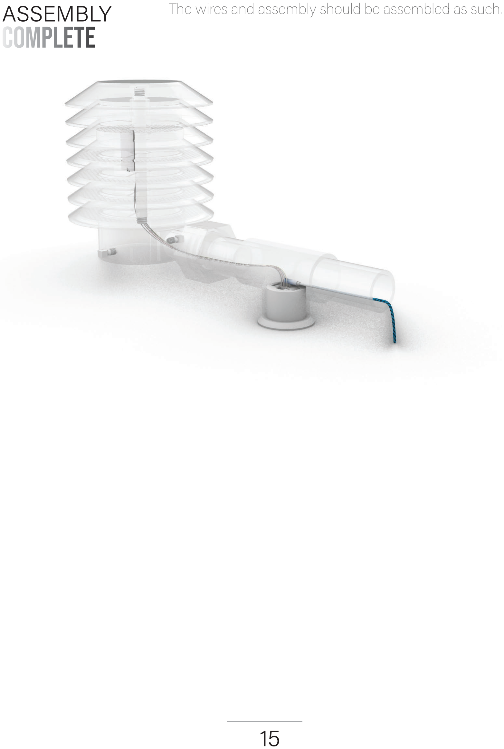
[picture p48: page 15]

ASSEMBLY | The wires and assembly should be assembled as such.

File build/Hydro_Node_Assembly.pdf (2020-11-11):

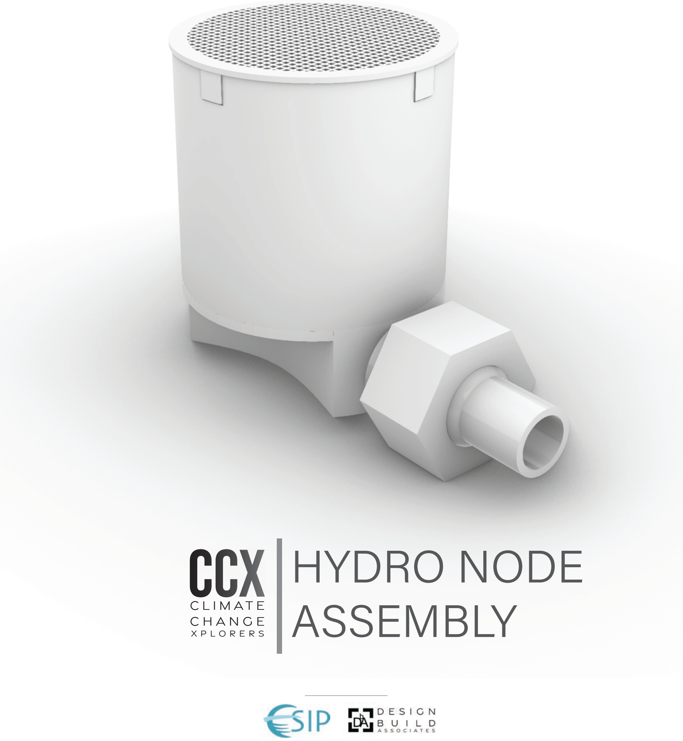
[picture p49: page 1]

# HYDRO NODE ASSEMBLY Climate

Change
xplorers

# CCX

Climate
Change
xplorers

## EXPLODED COMPONENTS

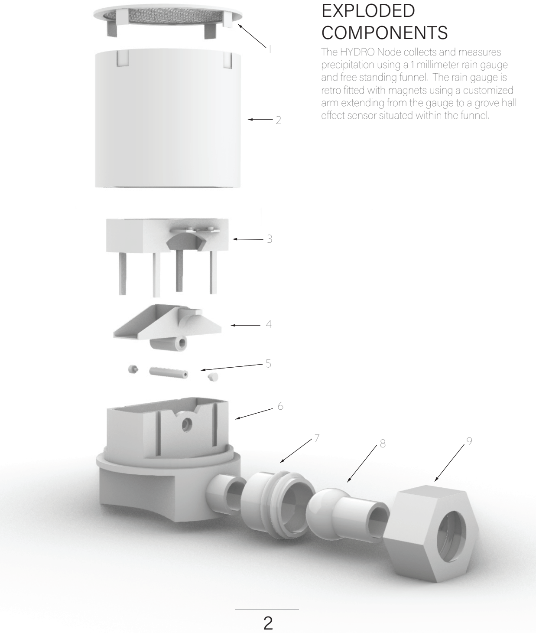
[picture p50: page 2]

The HYDRO Node collects and measures precipitation using a 1 millimeter rain gauge and free standing funnel. The rain gauge is retro fitted with magnets using a customized arm extending from the gauge to a grove hall eect sensor situated within the funnel.

1

2

3

7 | 8

6

9

5

4

## COMPONENTS LIST

## ASSEMBLY

# | DESCRITION | QUANTITY

1 | Funnel Screen | 1
2 | Funnel | 1
3 | Hydro Slot | 1
4 | Hydro Gauge | 1
5 | Fulcrum | 1
6 | Hydro Base | 1
7 | Swivel Innerlock | 1
8 | Swivel Ball Joint Bar | 1
9 | Swivel Outerlock | 1

# STEP 1

Align the holes in the Hydro Gauge with holes in the center of the Hydro Base and insert the Fulcrum into the hole in the center of the Gauge. Secure the fulcrum by snapping the pins in on both sides.

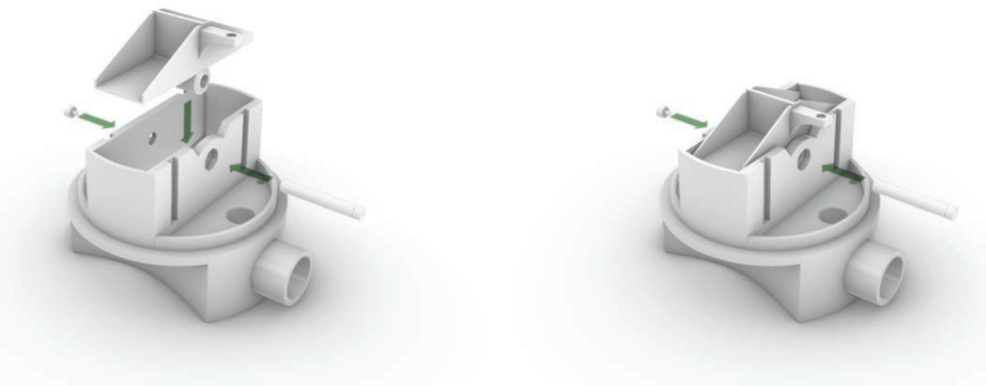
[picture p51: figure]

## ASSEMBLY

# STEP 2

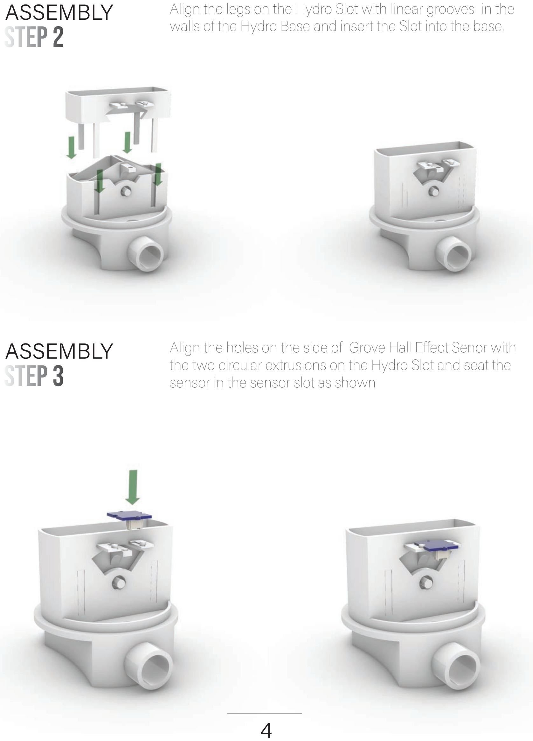
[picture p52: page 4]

## ASSEMBLY

# STEP 3

Align the holes on the side of Grove Hall Eect Senor with the two circular extrusions on the Hydro Slot and seat the sensor in the sensor slot as shown

Align the legs on the Hydro Slot with linear grooves in the walls of the Hydro Base and insert the Slot into the base.

## ASSEMBLY

# STEP 4

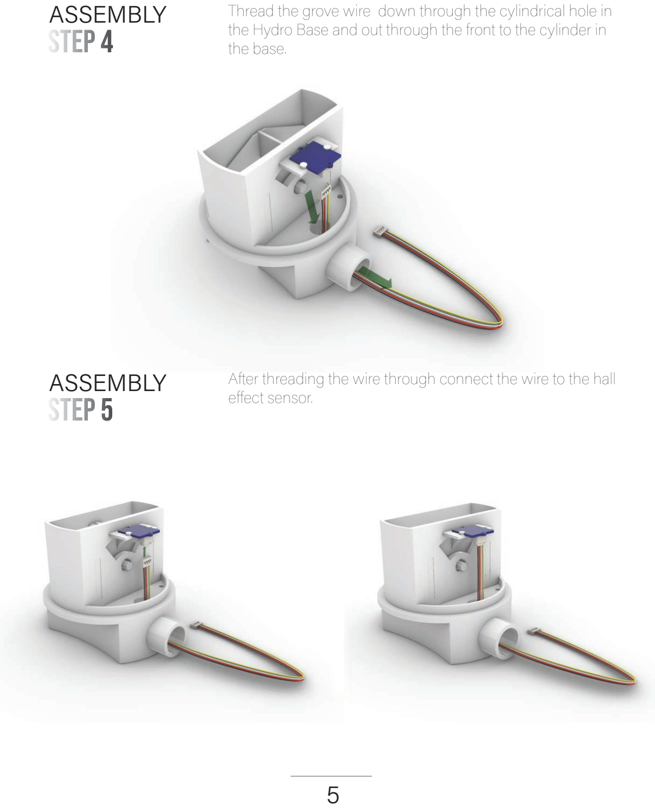
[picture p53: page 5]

## ASSEMBLY

# STEP 5

After threading the wire through connect the wire to the hall eect sensor.

Thread the grove wire down through the cylindrical hole in the Hydro Base and out through the front to the cylinder in the base.

## ASSEMBLY

# STEP 6

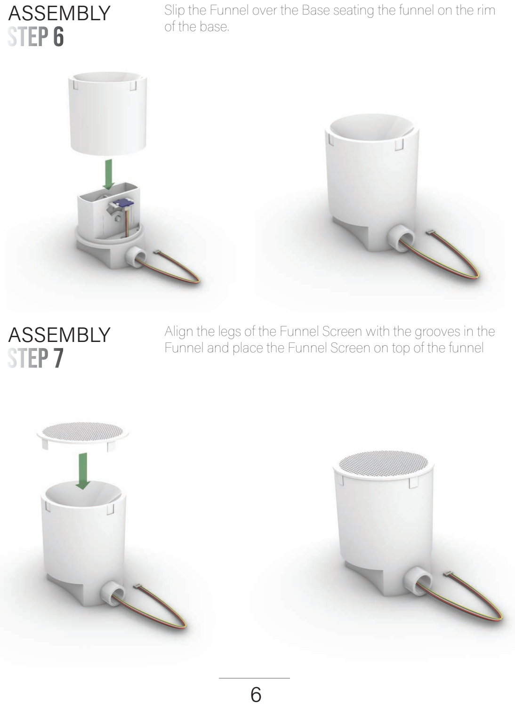
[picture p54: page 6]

## ASSEMBLY

# STEP 7

Align the legs of the Funnel Screen with the grooves in the Funnel and place the Funnel Screen on top of the funnel

Slip the Funnel over the Base seating the funnel on the rim of the base.

## ASSEMBLY

# STEP 8


## ASSEMBLY

# STEP 9

Cut a 3 inch piece of 1” diameter PVC and slot it on to the end of the Swivel Joint assembly ensuring that the grove wire is flowing through the PVC.

Align the Swivel Innerlock, Ball-joint Bar, and Outerlock respectively and assemble by twisting the outerlock onto the innerlock until tight with the ball-joint bar in between. Then push the swivel assembly on the cylinder of the base allowing the grove wire to pass through the assembly..

## ASSEMBLY

# STEP 10


## ASSEMBLY

# STEP 11

Insert the USB-C power Cord onto the PVC T-Joint ensuring that the cord is coming out through the bottom of the T-Joint.

Place your PVC T-Joint onto the smaller PVC ensuring that the grove wire flows out of the bottom of the T-Joint.

## ASSEMBLY

# STEP 12


## ASSEMBLY

# STEP 13

Connect the Micro controller to the Grove Cord and the Power Cord

Cut a second 3” piece of 1” PVC and attach it to the T-Joint ensuring that the power cord is flowing through the end of the PVC.

## ASSEMBLY

# STEP 14


## ASSEMBLY

# STEP 15

Push the Micro Holder into the T-Joint and assembly is complete.

Slot the Connected Microcontoller into the Micro Holder.

## ASSEMBLY

# COMPLETE

The Grove Cords and Power Cords Should run through the Assembles Hydro Module as shown.


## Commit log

2020-07-23 added stl files for original hydro node
    [rain_bucket.stl, rain_fulcrum.stl, rain_pin.stl]
2020-07-23 updated original atmos files
    [rs_base.stl, rs_center_screen.stl, rs_clip.stl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]
2020-08-12 renamed _screen to _shaft
    [rs_shaft.stl]
2020-08-13 update print table
2020-08-13 update with swivel ball joint
2020-08-13 removed old files, updated readme
    [rain_bucket.stl, rain_fulcrum.stl, rain_pin.stl]
2020-08-15 updated readme for stl
2020-11-06 updated stl files
    [pvc_balljoint_bar.stl, pvc_en_cap.stl, pvc_en_tube.stl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]
2020-11-11 updated documentation
    [aero_wnvn_clips_3.stl, aero_wnvn_coupler_3.stl, aero_wnvn_plate_3.stl]
2020-11-11 updated assembly links
2020-11-12 updated clip files
    [aero_wnvn_clips_3.stl]
2021-01-25 updated cap for incomplete node
    [aero_wnvn_cap_2.stl]
2021-01-25 updated tripod base files
    [pvc_mid_splitter.stl, pvc_tri_splitter_2.stl, pvc_tripod_base_2.stl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]
